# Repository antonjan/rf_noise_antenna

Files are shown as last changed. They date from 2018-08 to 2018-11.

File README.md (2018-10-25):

# rf_noise_antenna
This repository will have all the details for the active antenna board for Rasdpberry PI<br>
This project will have the Raspberry Pi HAT that will switch in the LOW and HIGH pass filters depending on IO-PIN4 on raspberry Pi.<br>
What is still missing from this project is the actual active antenna.<br>
<b>RF Noise Block Diagram</b><br>
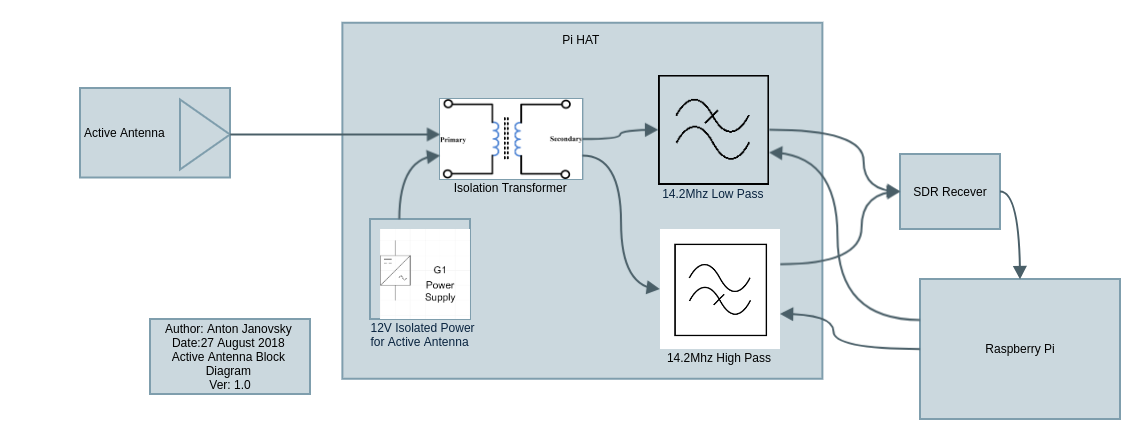
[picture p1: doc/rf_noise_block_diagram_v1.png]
Block Diagram Block Diagram
<br>
There is also a Isolation transformer on the board to eliminate the DC ground from the antenna and generating noise.<br>
This antenna consists of a raspberry HAT for RF filter and power injection for the active Antenna.<br>
<br>
# Project Status
This Project is Now Compleet. (The PCB Board still needs to be build and Tested)<br>
# Live Monitoring system
<a href="http://rfnoise.amsatsa.org.za/">http://rfnoise.amsatsa.org.za/</a><br>
# More Documentation
<a href="https://github.com/antonjan/rf_noise_antenna/tree/master/doc">More Dokuments click here</a><br>
<b>Diagram of Active antenna base filter.</b><br>
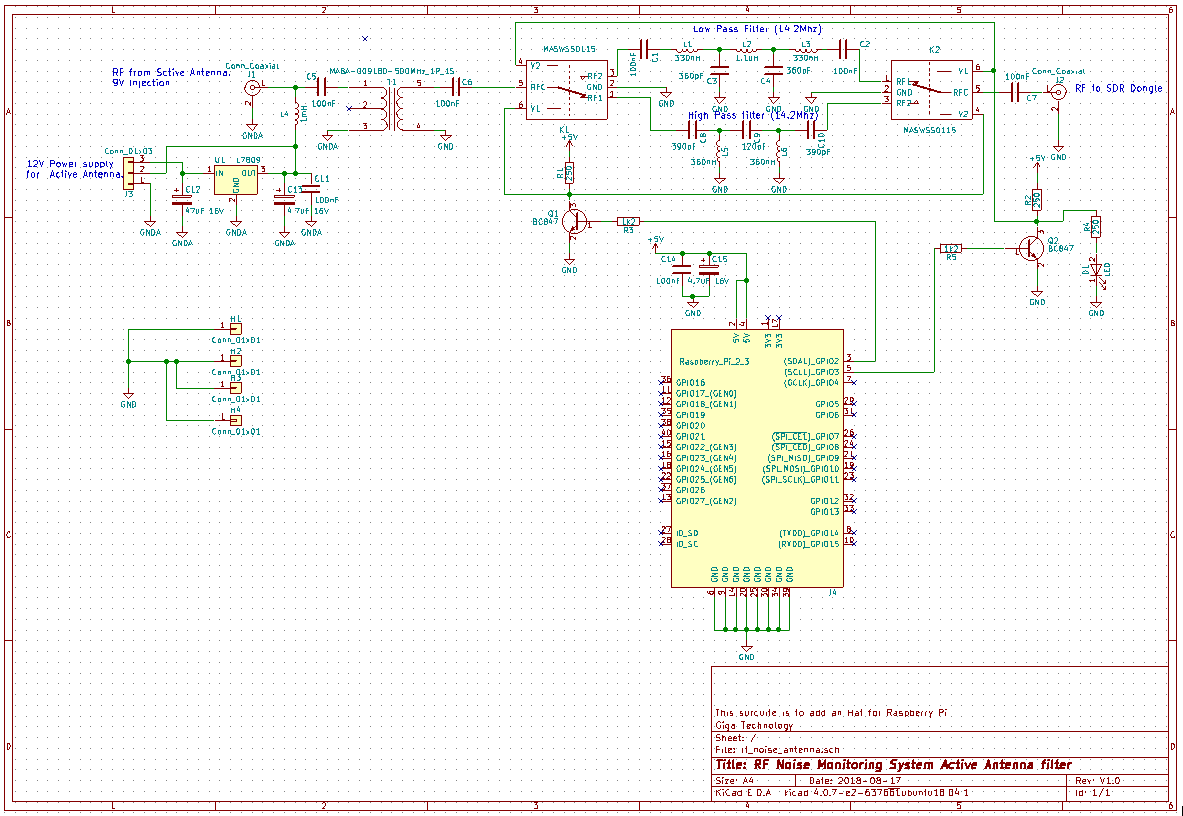
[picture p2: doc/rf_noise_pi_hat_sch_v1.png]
Diagram
<br><br>
PCB Layout<br>
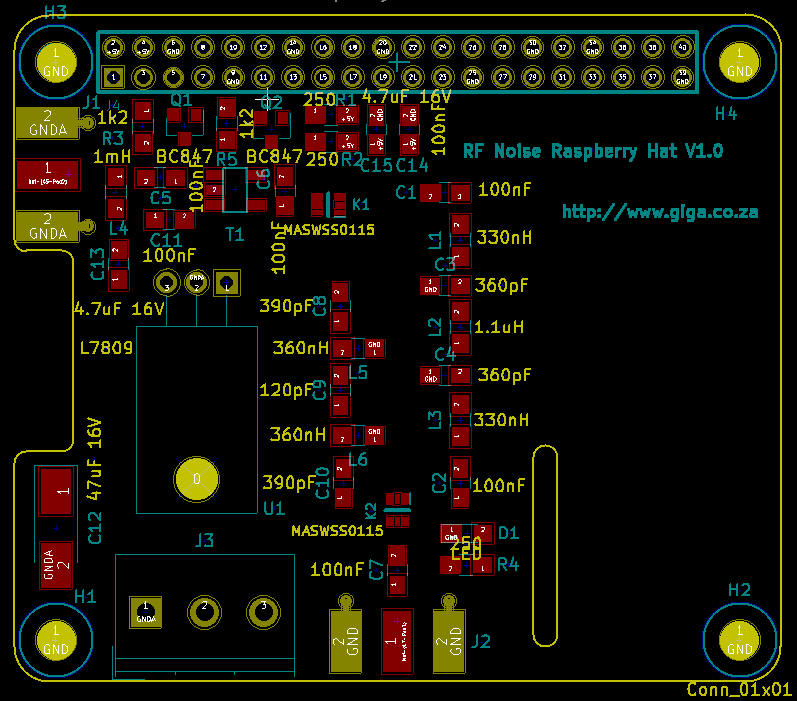
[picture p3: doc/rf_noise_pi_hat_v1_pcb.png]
<br><br>
<b>PCB Layout</b><br>
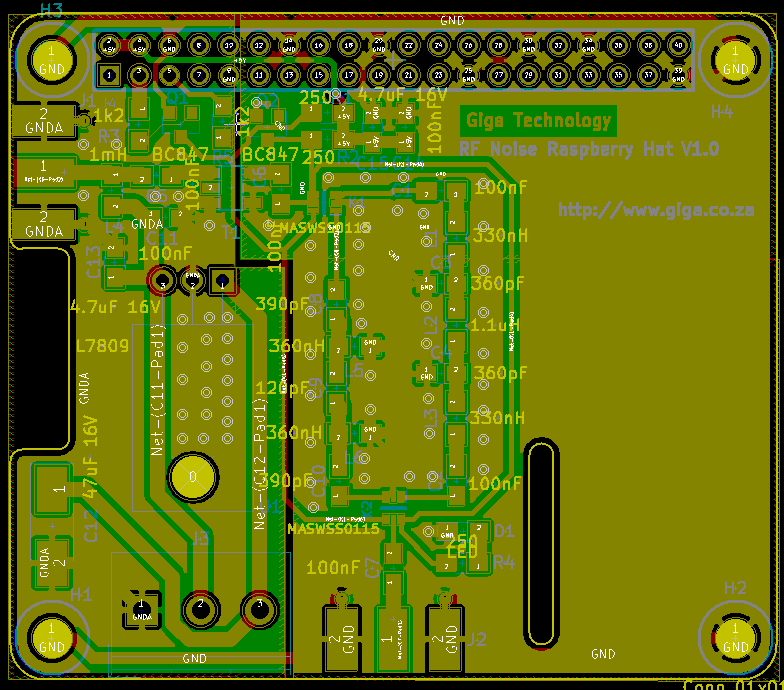
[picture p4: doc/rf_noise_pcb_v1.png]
<br><br>
<b>PCB Layout 3D</b><br>
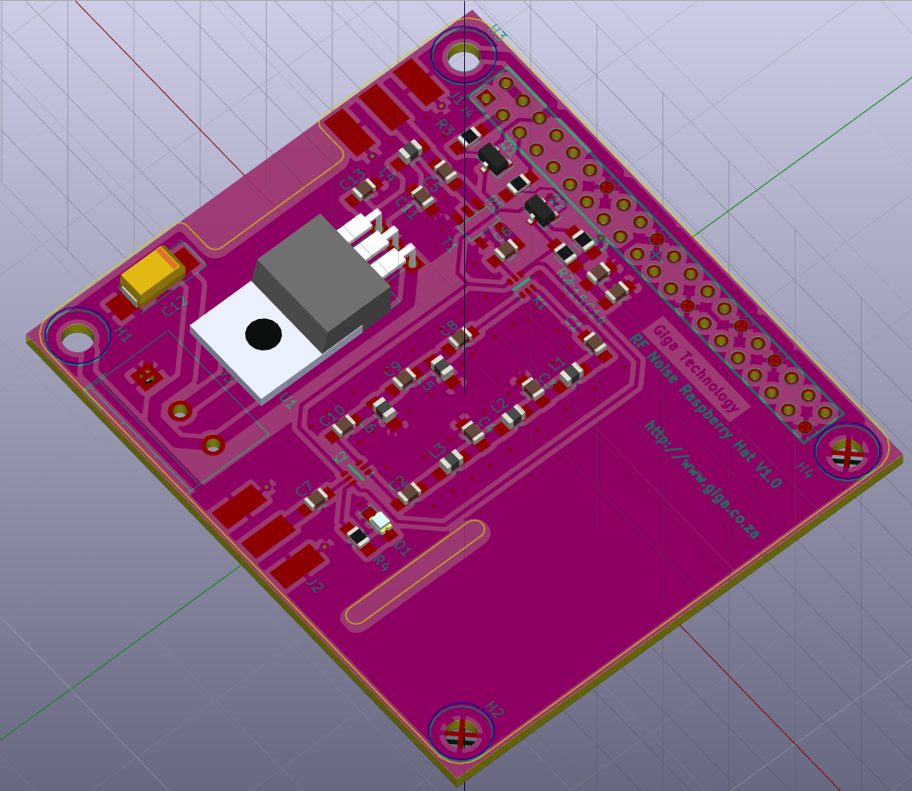
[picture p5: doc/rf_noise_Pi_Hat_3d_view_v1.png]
PCB PCB Layout 3D
<br><br>
<b>Filter Low PASS</b><br>
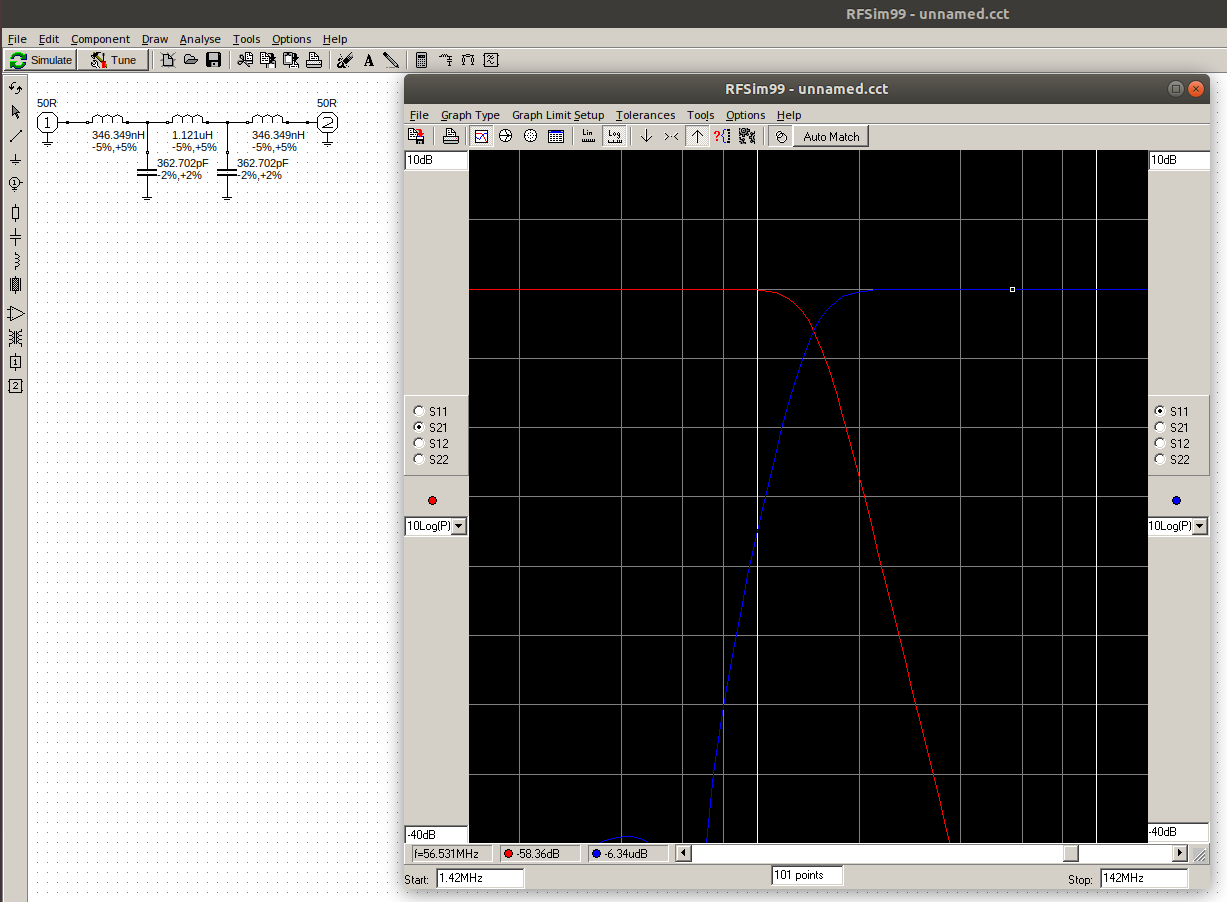
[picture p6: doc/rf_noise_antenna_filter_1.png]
Filter 1
<br><br>
<b>Filter High PASS</b><br>
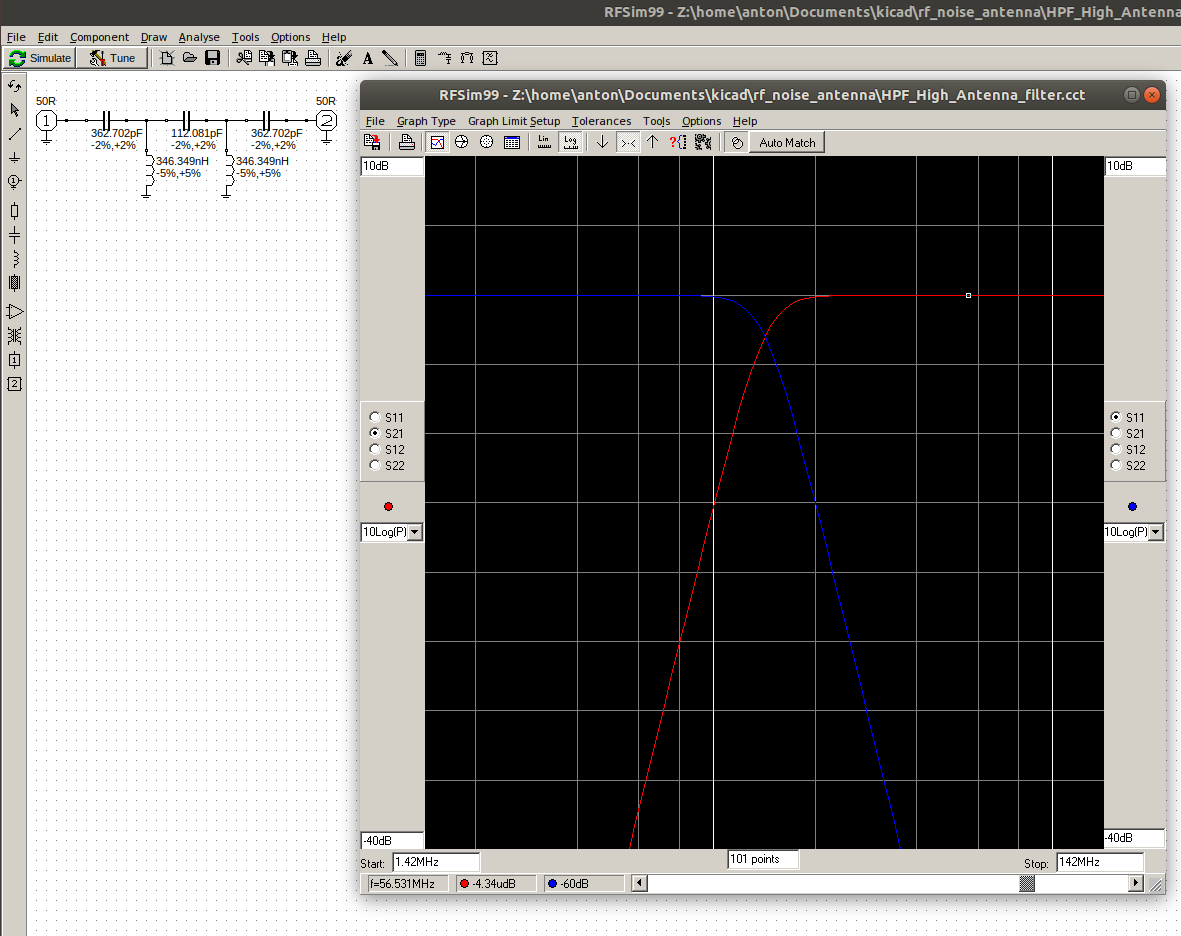
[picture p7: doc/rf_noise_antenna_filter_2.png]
Filter 2
<br><br>
<br>

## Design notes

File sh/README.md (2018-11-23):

# This testing scripts to controle the Antenna switch on RF Noise Antenna filter Board.
The antenna_loop_test.sh will swiche between the two antennas every 1 second just to test that the LED's activate

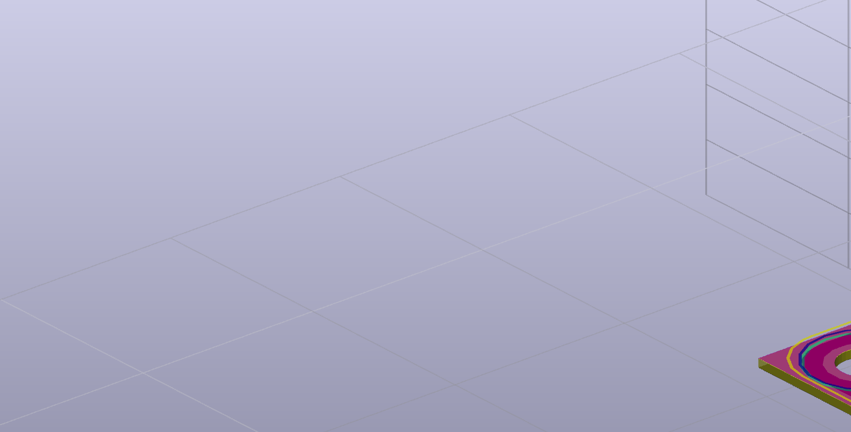
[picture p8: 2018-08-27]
doc/rf_noise_antenna_3d_view_v1.png

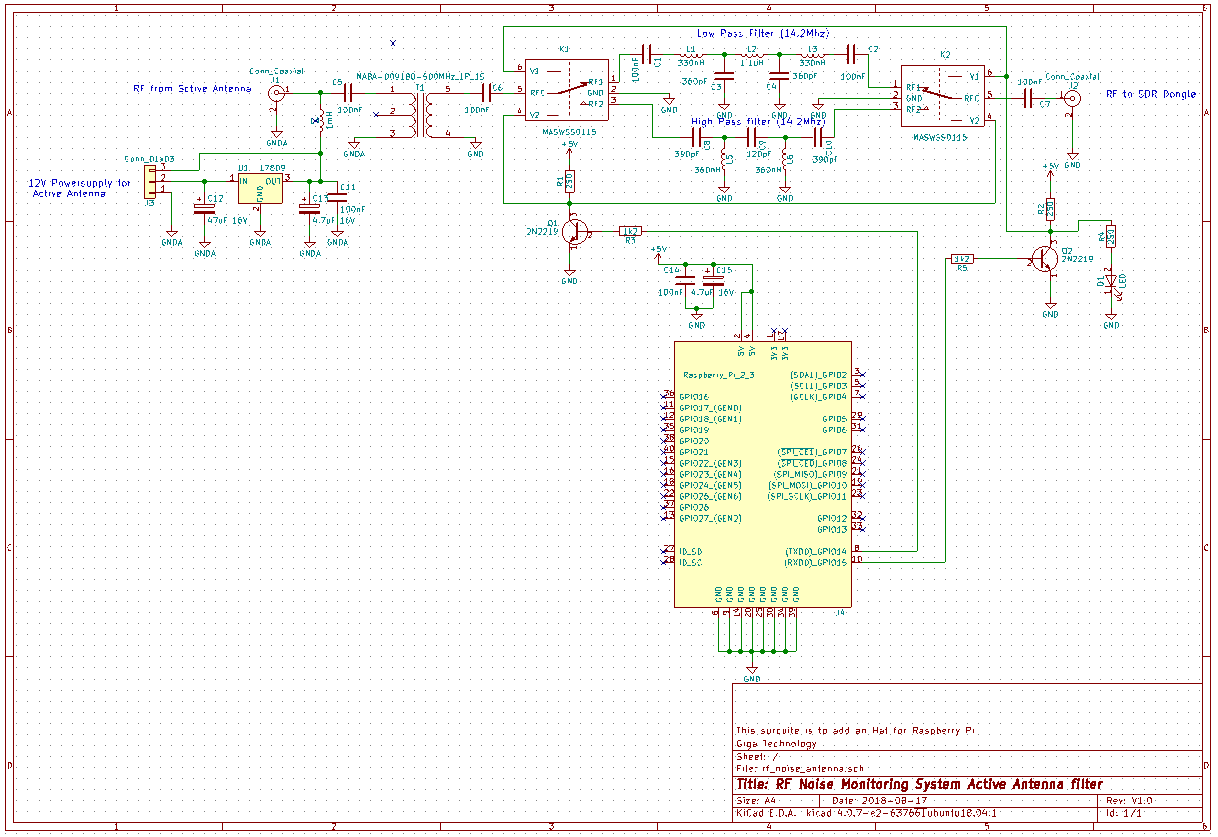
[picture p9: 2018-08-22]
doc/rf_noise_antenna_3.png

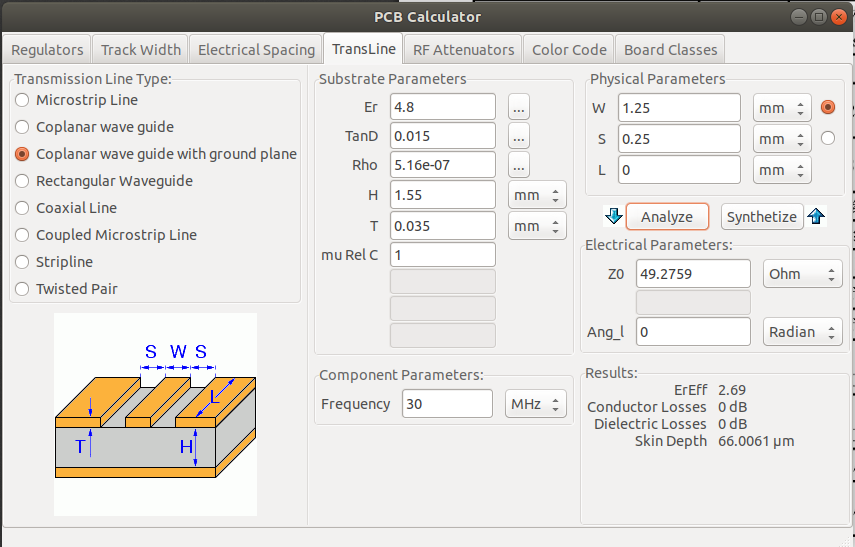
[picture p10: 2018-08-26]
doc/Transmition_Line_30Mhz.png

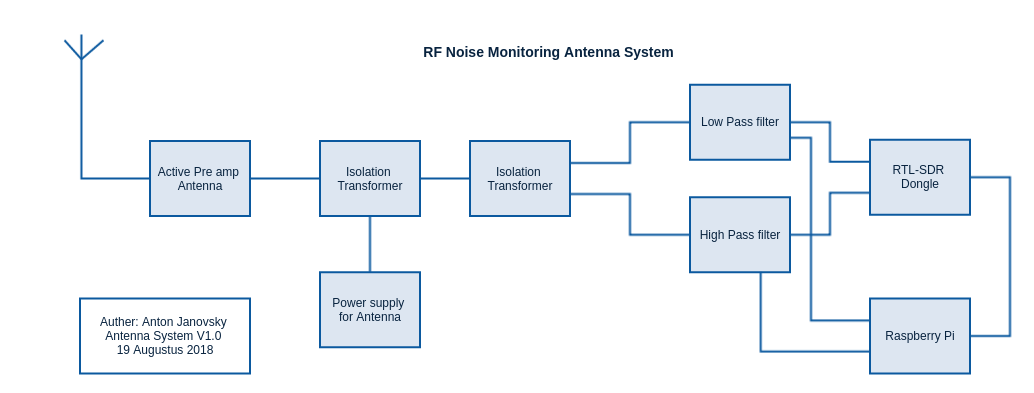
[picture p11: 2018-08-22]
gliffy/RF_Antenna_System_v1_0.png

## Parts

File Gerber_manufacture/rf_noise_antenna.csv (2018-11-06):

Id | Designator | Package | Quantity | Designation | Supplier and ref
1 | J1,J2 | Molex_SMA_Jack_Edge_Mount | 2 | Conn_Coaxial
2 | J4 | PIN_ARRAY_20X2 | 1 | Raspberry_Pi_2_3
3 | C1,C2,C5,C6,C7,C11,C14 | C_0805_HandSoldering | 7 | 100nF
4 | C3,C4 | C_0805_HandSoldering | 2 | 360pF
5 | C8,C10 | C_0805_HandSoldering | 2 | 390pF
6 | C9 | C_0805_HandSoldering | 1 | 120pF
7 | C12 | CP_Tantalum_Case-C_EIA-6032-28_Hand | 1 | 47uF 16V
8 | C13,C15 | C_0805_HandSoldering | 2 | 4.7uF 16V
9 | D1 | LED_0805_HandSoldering | 1 | LED
10 | J3 | TerminalBlock_Philmore_TB133_03x5mm_Straight | 1 | Conn_01x03
11 | K1,K2 | SC-70-6 | 2 | MASWSS0115
12 | L1,L3 | L_0805_HandSoldering | 2 | 330nH
13 | L2 | L_0805_HandSoldering | 1 | 1.1uH
14 | L4 | L_0805_HandSoldering | 1 | 1mH
15 | L5,L6 | L_0805_HandSoldering | 2 | 360nH
16 | R1,R2,R4 | R_0805_HandSoldering | 3 | 250
17 | R3,R5 | R_0805_HandSoldering | 2 | 1k2
18 | T1 | SM22 | 1 | MABA-009180-500MHz_1P_1S
19 | H1,H2,H3,H4 | MountingHole_3.2mm_M3 | 4 | Conn_01x01
20 | Q1,Q2 | SOT-23 | 2 | BC847
21 | U1 | TO-220_Horizontal | 1 | L7809

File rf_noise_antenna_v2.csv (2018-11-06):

Id | Designator | Package | Quantity | Designation | Supplier and ref
1 | J4 | PIN_ARRAY_20X2 | 1 | Raspberry_Pi_2_3
2 | C1,C2,C5,C6,C7,C11,C14 | C_0805_HandSoldering | 7 | 100nF
3 | C3,C4 | C_0805_HandSoldering | 2 | 360pF
4 | C8,C10 | C_0805_HandSoldering | 2 | 390pF
5 | C9 | C_0805_HandSoldering | 1 | 120pF
6 | C12 | CP_Tantalum_Case-C_EIA-6032-28_Hand | 1 | 47uF 16V
7 | C13,C15 | C_0805_HandSoldering | 2 | 4.7uF 16V
8 | D1,D2 | LED_0805_HandSoldering | 2 | LED
9 | J3 | TerminalBlock_Philmore_TB133_03x5mm_Straight | 1 | Conn_01x03
10 | K1,K2 | SC-70-6 | 2 | MASWSS0115
11 | L1,L3 | L_0805_HandSoldering | 2 | 330nH
12 | L2 | L_0805_HandSoldering | 1 | 1.1uH
13 | L4 | L_0805_HandSoldering | 1 | 10uH
14 | L5,L6 | L_0805_HandSoldering | 2 | 360nH
15 | R1,R2,R4,R6 | R_0805_HandSoldering | 4 | 250
16 | R3,R5 | R_0805_HandSoldering | 2 | 1k2
17 | T1 | SM22 | 1 | MABA-009180-500MHz_1P_1S
18 | H1,H2,H3,H4 | MountingHole_3.2mm_M3 | 4 | Conn_01x01
19 | Q1,Q2 | SOT-23 | 2 | BC847
20 | U1 | TO-220_Horizontal | 1 | L7812
21 | J1,J2 | SMA_Edge | 2 | Conn_Coaxial
22 | REF**,REF**,REF**,REF** | MountingHole_3.2mm_M3 | 4 | MountingHole_3.2mm_M3

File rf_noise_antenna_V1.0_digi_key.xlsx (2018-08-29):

Component | Description | Manufacturere Pnr | Part | References | Value | Footprint | Quantity Per PCB | Datasheet
1 | Unpolarized capacitor | 399-1122-1-ND (https://www.digikey.co.za/product-detail/en/kemet/C0805C101J5GACTU/399-1122-1-ND/411397) | C | C1 C2 C5 C6 C7 C11 C14 | 100nF | C_0805_HandSoldering | 7
2 | Unpolarized capacitor | 1276-1768-1-ND (https://www.digikey.co.za/product-detail/en/samsung-electro-mechanics/CL21C121JBANNNC/1276-1768-1-ND/3889854) | C | C9 | 120pF | C_0805_HandSoldering | 1
3 | Unpolarized capacitor | 1276-2650-1-ND (https://www.digikey.co.za/product-detail/en/samsung-electro-mechanics/CL21C361JBANNNC/1276-2650-1-ND/3890736) | C | C3 C4 | 360pF | C_0805_HandSoldering | 2
4 | Unpolarized capacitor | 1276-2510-1-ND (https://www.digikey.co.za/product-detail/en/samsung-electro-mechanics/CL21B391KBANNNC/1276-2510-1-ND/3890596) | C | C8 C10 | 390pF | C_0805_HandSoldering | 2
5 | Polarised capacitor | 1276-1065-1-ND (https://www.digikey.co.za/product-detail/en/samsung-electro-mechanics/CL21A475KOFNNNE/1276-1065-1-ND/3889151) | CP | C13 C15 | 4.7uF 16V | C_0805_HandSoldering | 2
6 | Polarised capacitor | 718-1042-1-ND (https://www.digikey.co.za/product-detail/en/vishay-sprague/293D106X0016C2TE3/718-1042-1-ND/1559536) | CP | C12 | 47uF 16V | CP_Tantalum_Case-C_EIA-6032-28_Hand | 1
7 | LED generic | 67-1710-1-ND (https://www.digikey.co.za/product-detail/en/lumex-opto-components-inc/SML-LXR85SIC-TR/67-1710-1-ND/467594) | LED | D1 D2 | LED | LED_0805_HandSoldering | 2
8 | Generic connector, single row, 01x03 | 732-5316-ND (https://www.digikey.co.za/product-detail/en/wurth-electronics-inc/61300311121/732-5316-ND/4846825) | Conn_01x03 | J3 | Conn_01x03 | TerminalBlock_Philmore_TB133_03x5mm_Straight | 1
9 | coaxial connector (BNC, SMA, SMB, SMC, Cinch/RCA, ...) | 931-1175-ND (https://www.digikey.co.za/product-detail/en/taoglas-limited/EMPCB.SMAFSTJ.B.HT/931-1175-ND/3522337) | Conn_Coaxial | J1 J2 | Conn_Coaxial | Molex_SMA_Jack_Edge_Mount | 2
10 | expansion header for Raspberry Pi 2 & 3 | S6106-ND (https://www.digikey.co.za/product-detail/en/sullins-connector-solutions/PPPC102LFBN-RC/S6106-ND/807245) | Raspberry_Pi_2_3 | J4 | Raspberry_Pi_2_3 | Pin_Header_Straight_2x20 | 1 | https://www.raspberrypi.org/documentation/hardware/raspberrypi/schematics/RPI-3B-V1_2-SCHEMATIC-REDUCED.pdf
11 |  | 1465-1373-1-ND (https://www.digikey.co.za/product-detail/en/m-a-com-technology-solutions/MASWSS0115TR-3000/1465-1373-1-ND/4430070) | MASWSS0115 | K1 K2 | MASWSS0115 | SC-70-6 | 2
12 | Inductor | 963-LBR2012T1R0M (https://www.mouser.co.za/ProductDetail/Taiyo-Yuden/LBR2012T1R0M) | L | L2 | 1.1uH (get only 1uH) | L_0805_HandSoldering | 1 | https://www.mouser.co.za/ProductDetail/Taiyo-Yuden/LBR2012T1R0M
13 | Inductor | 652-CV201210-100K (https://www.mouser.co.za/ProductDetail/Bourns/CV201210-100K) | L | L4 | 10uH | L_0805_HandSoldering | 1
14 | Inductor | 652-CE201210-R33J (https://www.mouser.co.za/ProductDetail/Bourns/CE201210-R33J) | L | L1 L3 | 330nH | L_0805_HandSoldering | 2
15 | Inductor | 279-36502AR36JTDG (https://www.mouser.co.za/ProductDetail/TE-Connectivity-Sigma-Inductors/36502AR36JTDG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) | L | L5 L6 | 360nH | L_0805_HandSoldering | 2
16 | 45V Vce, 0.8A Ic, NPN, SOT-23 | BC847BRFGCT-ND (https://www.digikey.co.za/product-detail/en/taiwan-semiconductor-corporation/BC847B-RFG/BC847BRFGCT-ND/7357201) | BC847 | Q1 Q2 | BC847 | SOT-23 | 2 | http://www.fairchildsemi.com/ds/BC/BC817.pdf
17 | Resistor | 311-1.27KCRCT-ND (https://www.digikey.co.za/product-detail/en/yageo/RC0805FR-071K27L/311-1.27KCRCT-ND/730422) | R | R3 R5 | 1k2 | R_0805_HandSoldering | 2
18 | Resistor | RHM.27BSCT-ND (https://www.digikey.co.za/product-detail/en/rohm-semiconductor/LTR10EVHFLR270/RHM.27BSCT-ND/2708204) | R | R1 R2 R4 R6 | 250 | R_0805_HandSoldering | 4
19 | Transformer, single primary, single secondary | 1465-1793-1-ND (https://www.digikey.co.za/product-detail/en/m-a-com-technology-solutions/MABA-009180-500MHZ/1465-1793-1-ND/6575493) | MABA-009180-500MHz_1P_1S | T1 | MABA-009180-500MHz_1P_1S | SM22 | 1
20 | Positive 1.5A 35V Linear Regulator, Fixed Output 5V, TO-220/TO-263/TO-252 | LM7809ACT-ND (https://www.digikey.co.za/product-detail/en/on-semiconductor/LM7809ACT/LM7809ACT-ND/1923048) | L7809 | U1 | L7809 | TO-220_Horizontal | 1 | http://www.st.com/content/ccc/resource/technical/document/datasheet/41/4f/b3/b0/12/d4/47/88/CD00000444.pdf/files/CD00000444.pdf/jcr:content/translations/en.CD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
Component Groups: | 20
Component Count: | 39
Fitted Components: | 39
Number of PCBs: | 1
Total components: | 39
Schematic Version: | V1.0
Schematic Date: | 2018-08-17
BoM Date: | Wed 29 Aug 2018 09:54:15 SAST
Schematic Source: | /home/anton/Documents/kicad/rf_noise_antenna/rf_noise_antenna.sch
KiCad Version: | Eeschema 4.0.7-e2-6376~61~ubuntu18.04.1

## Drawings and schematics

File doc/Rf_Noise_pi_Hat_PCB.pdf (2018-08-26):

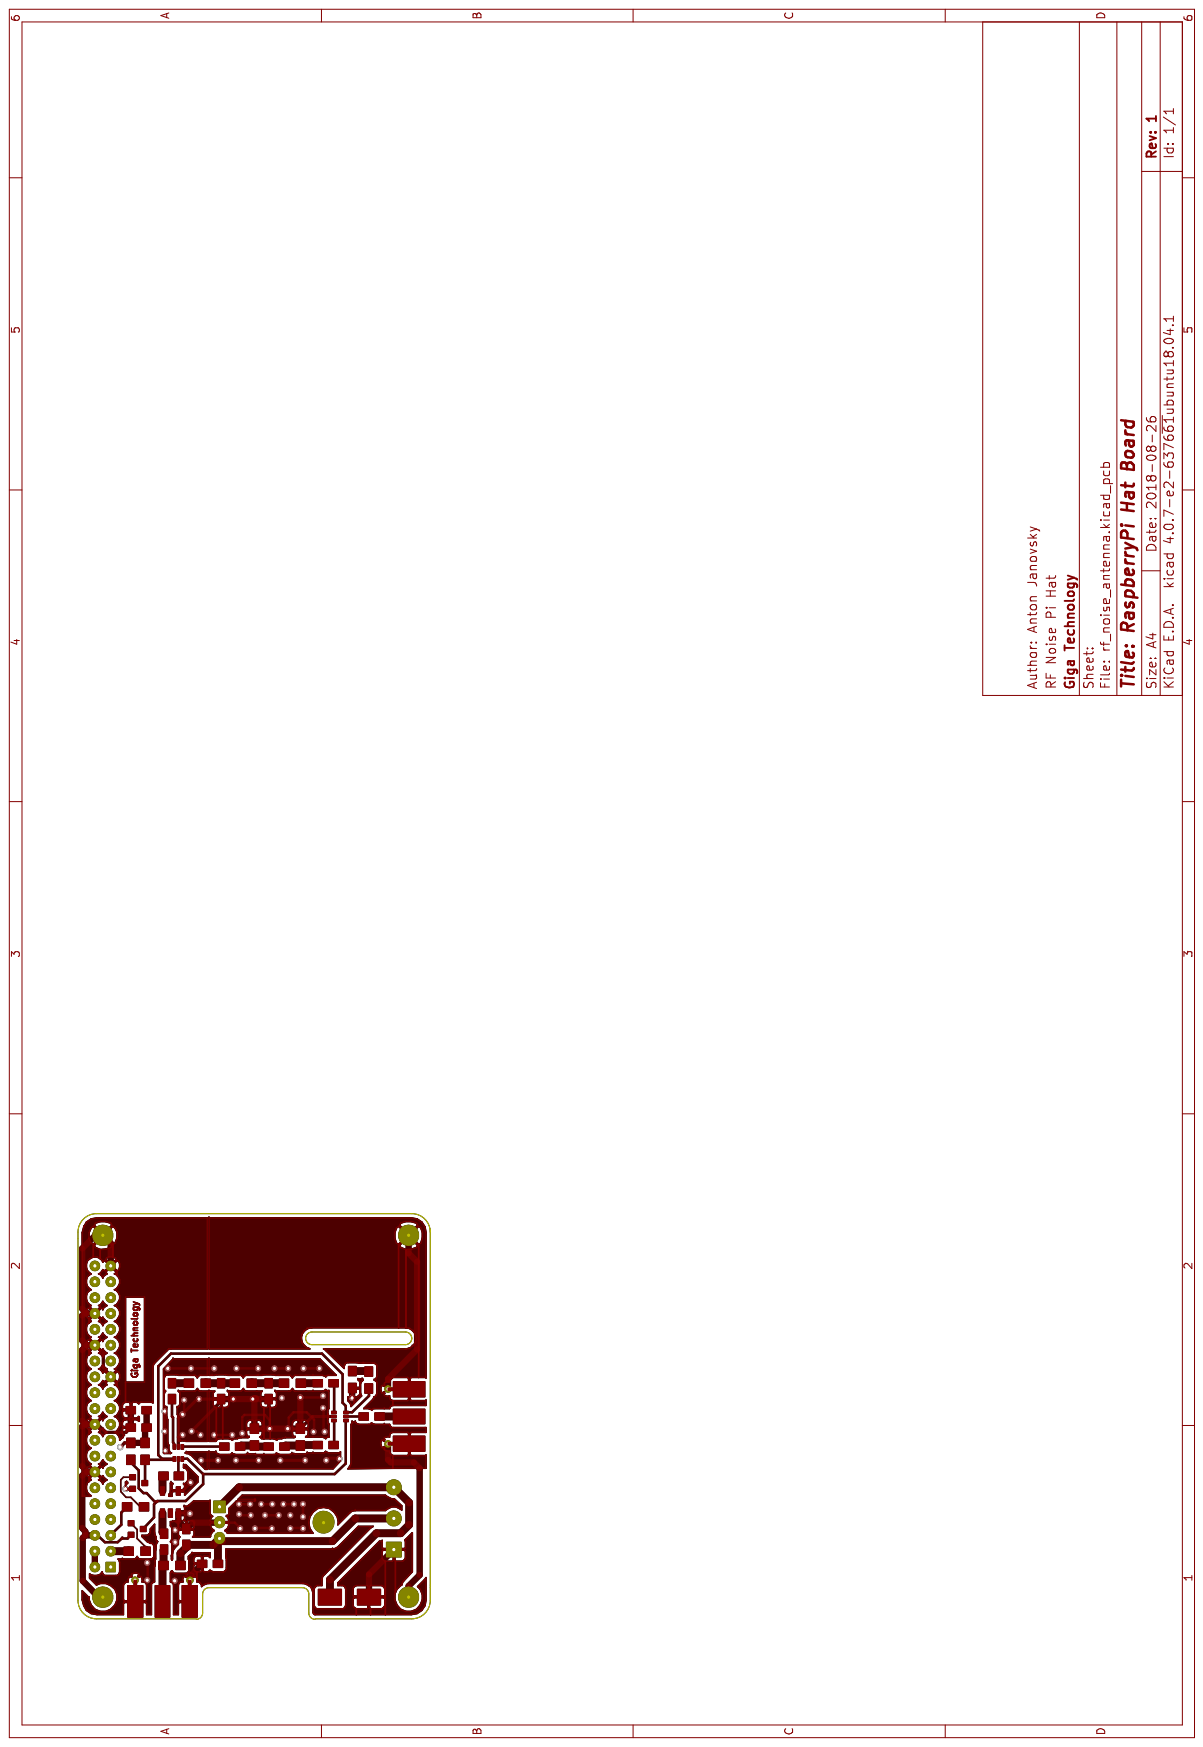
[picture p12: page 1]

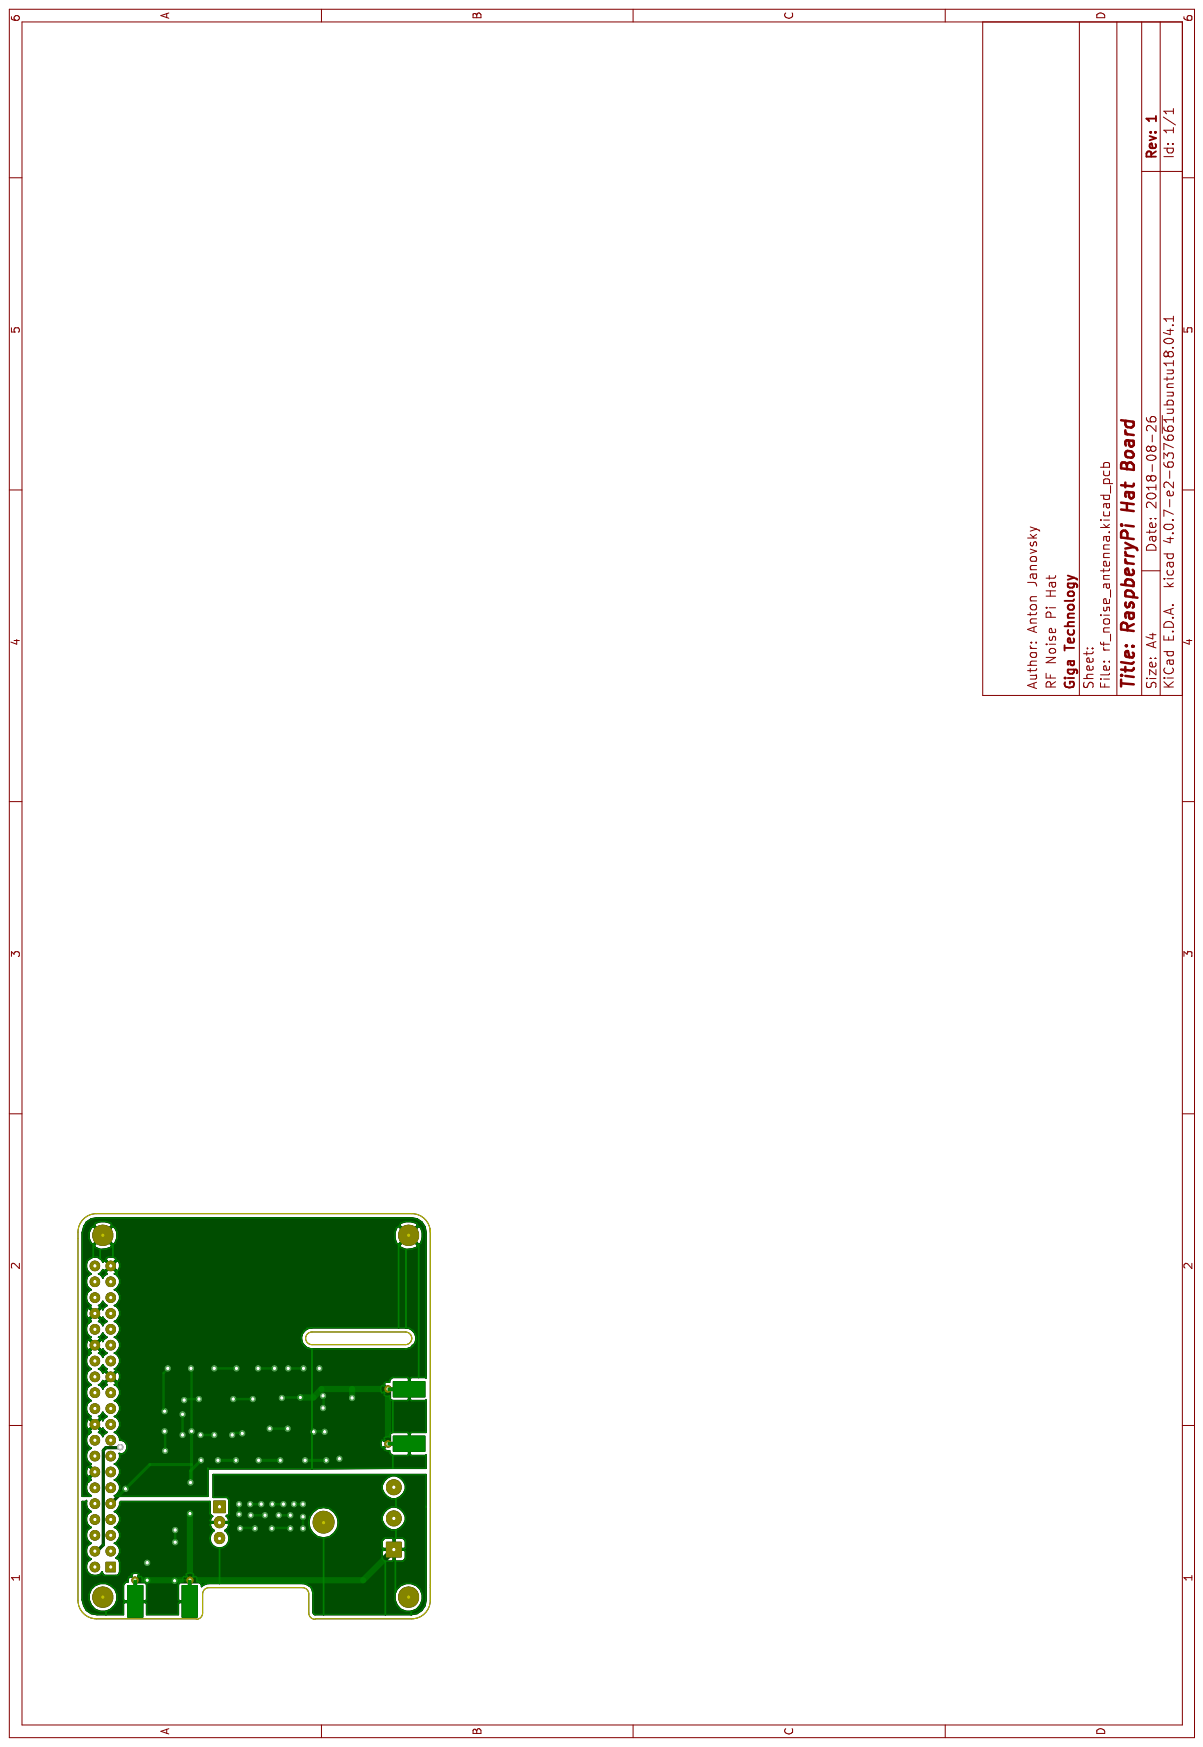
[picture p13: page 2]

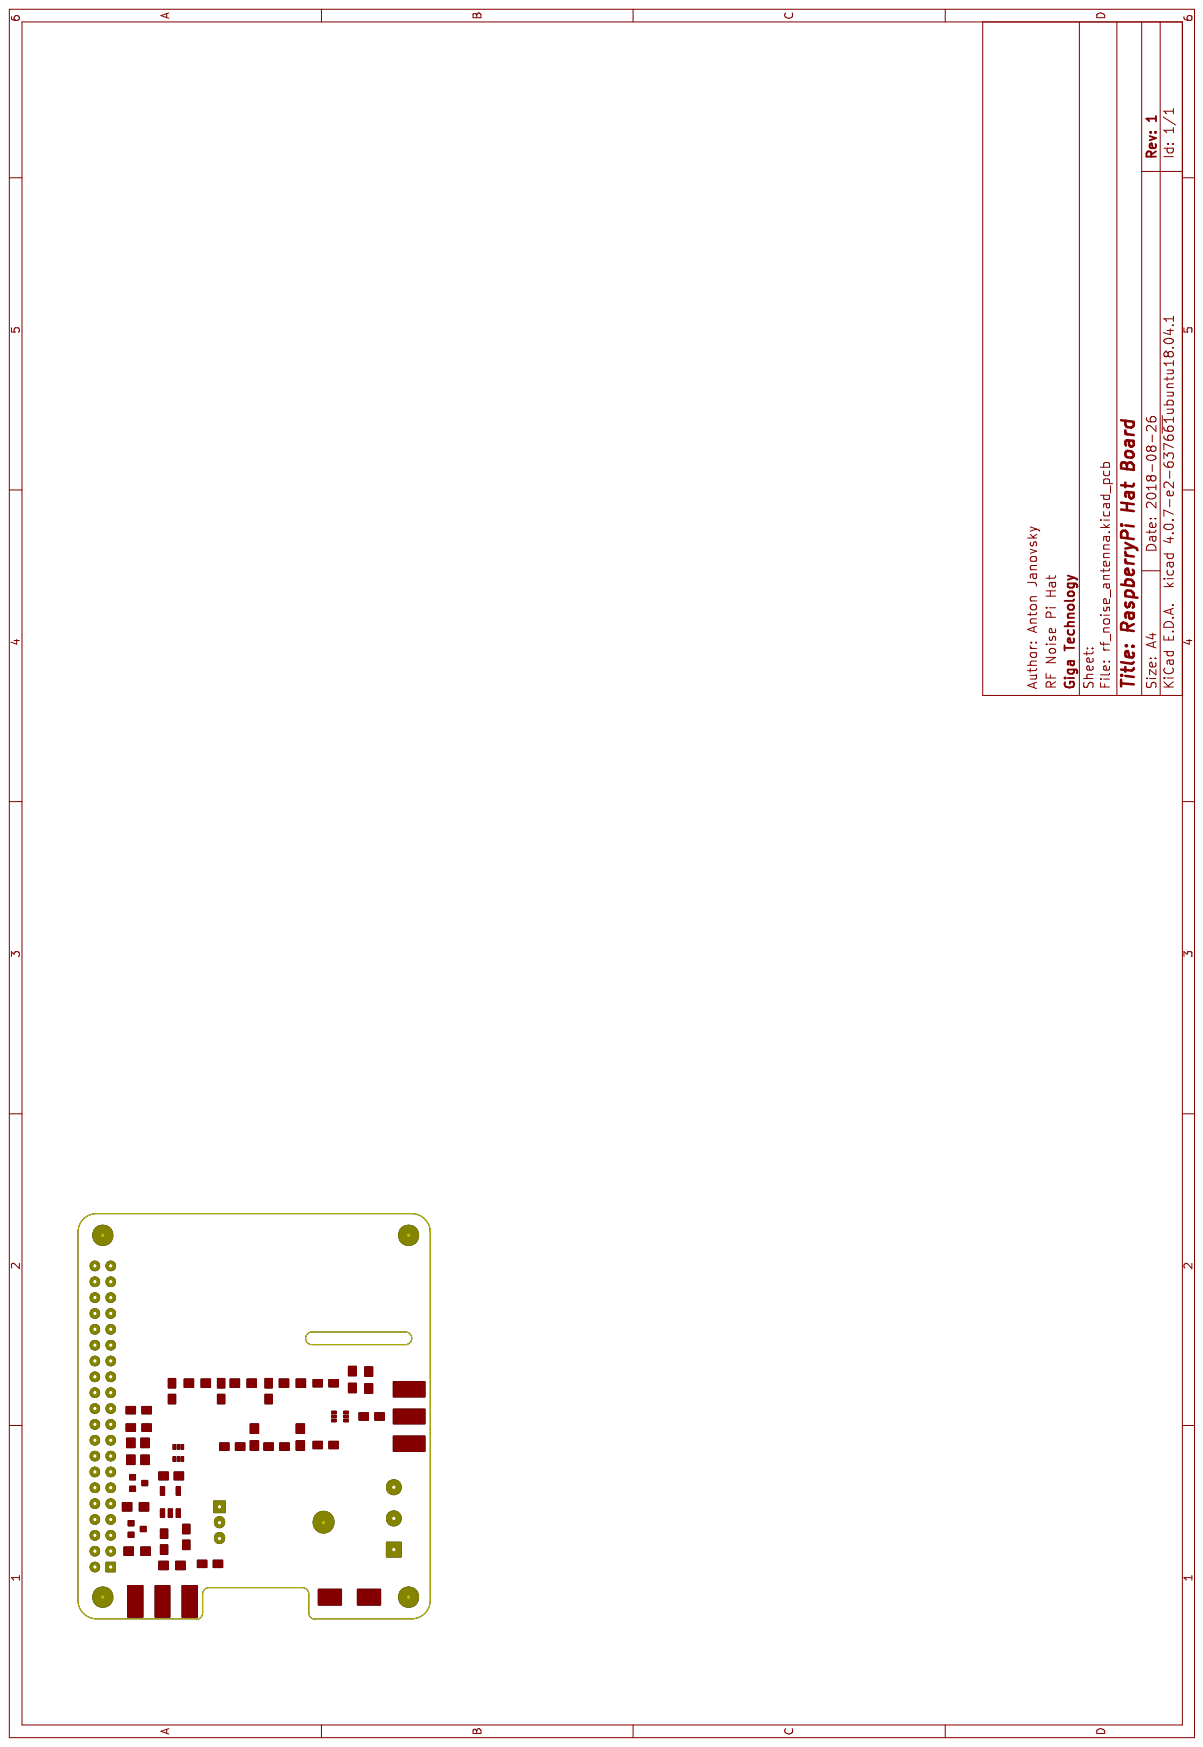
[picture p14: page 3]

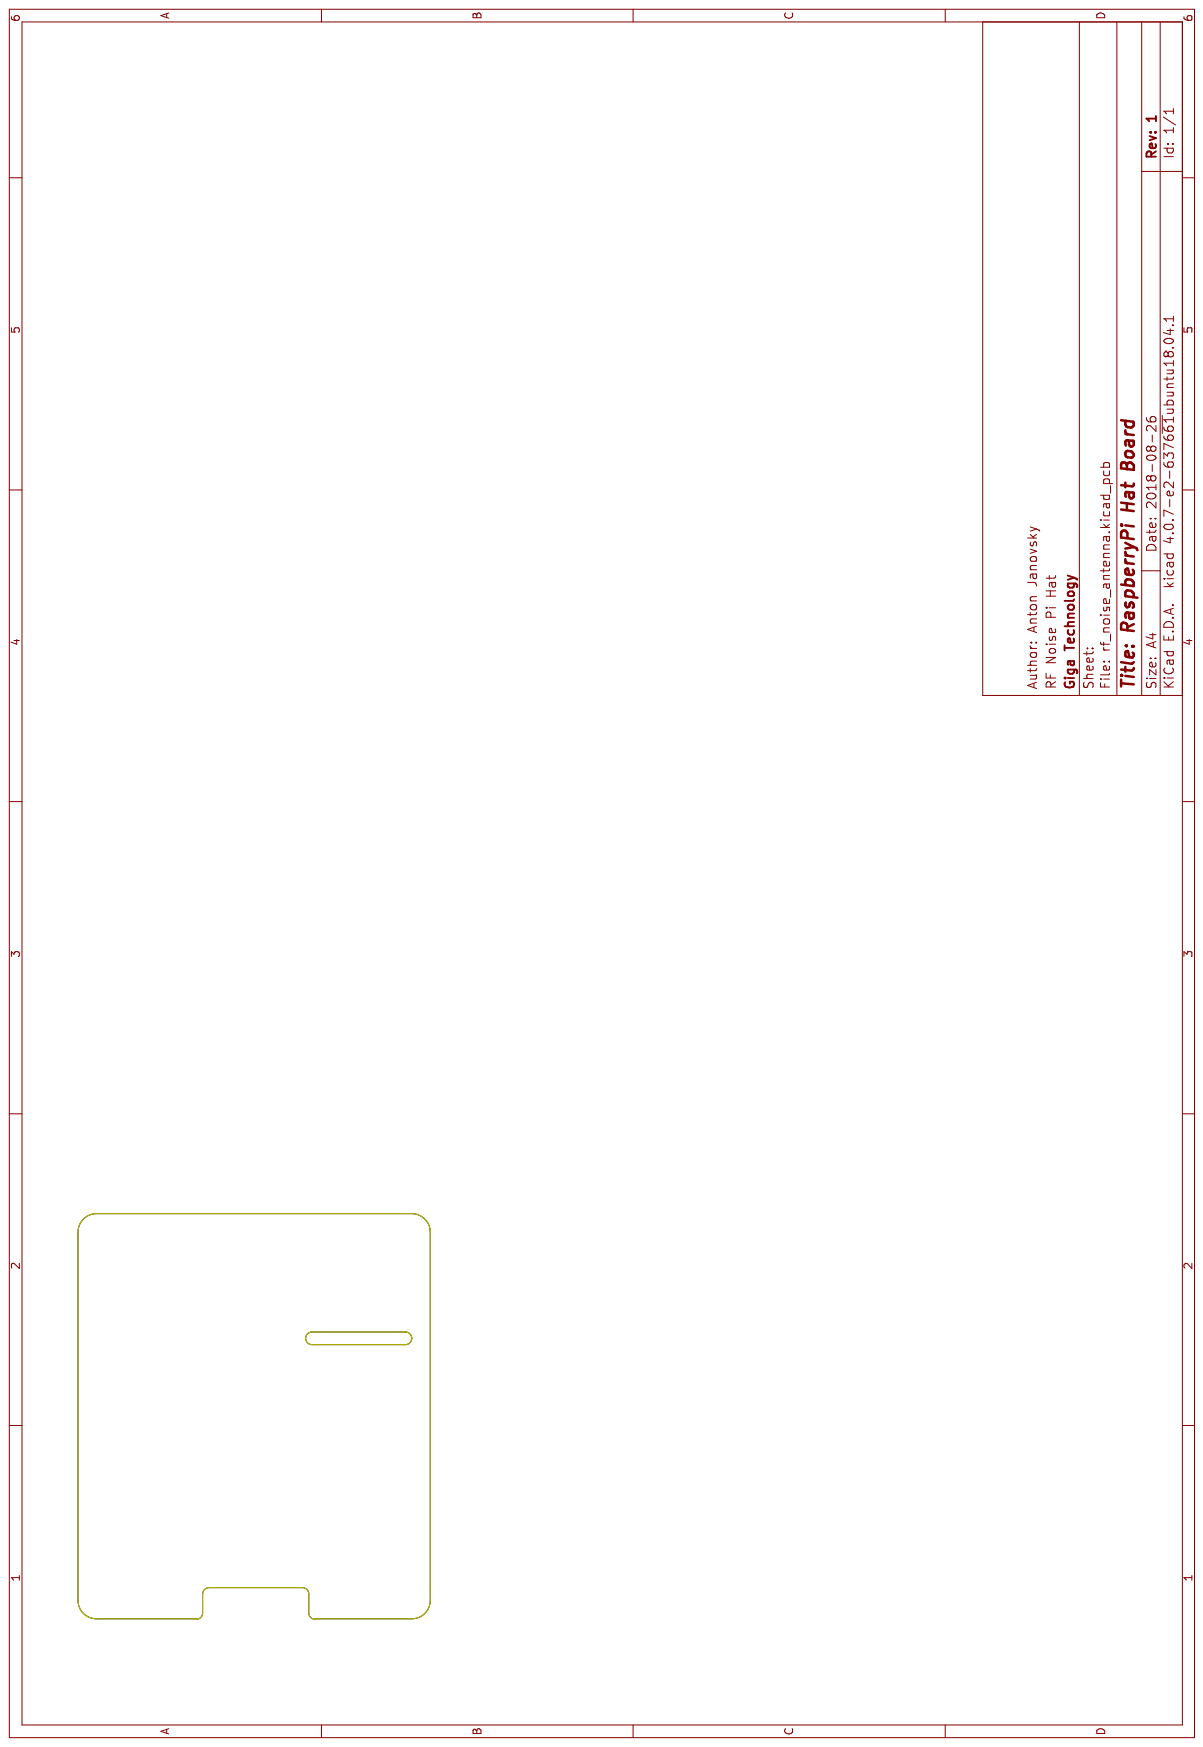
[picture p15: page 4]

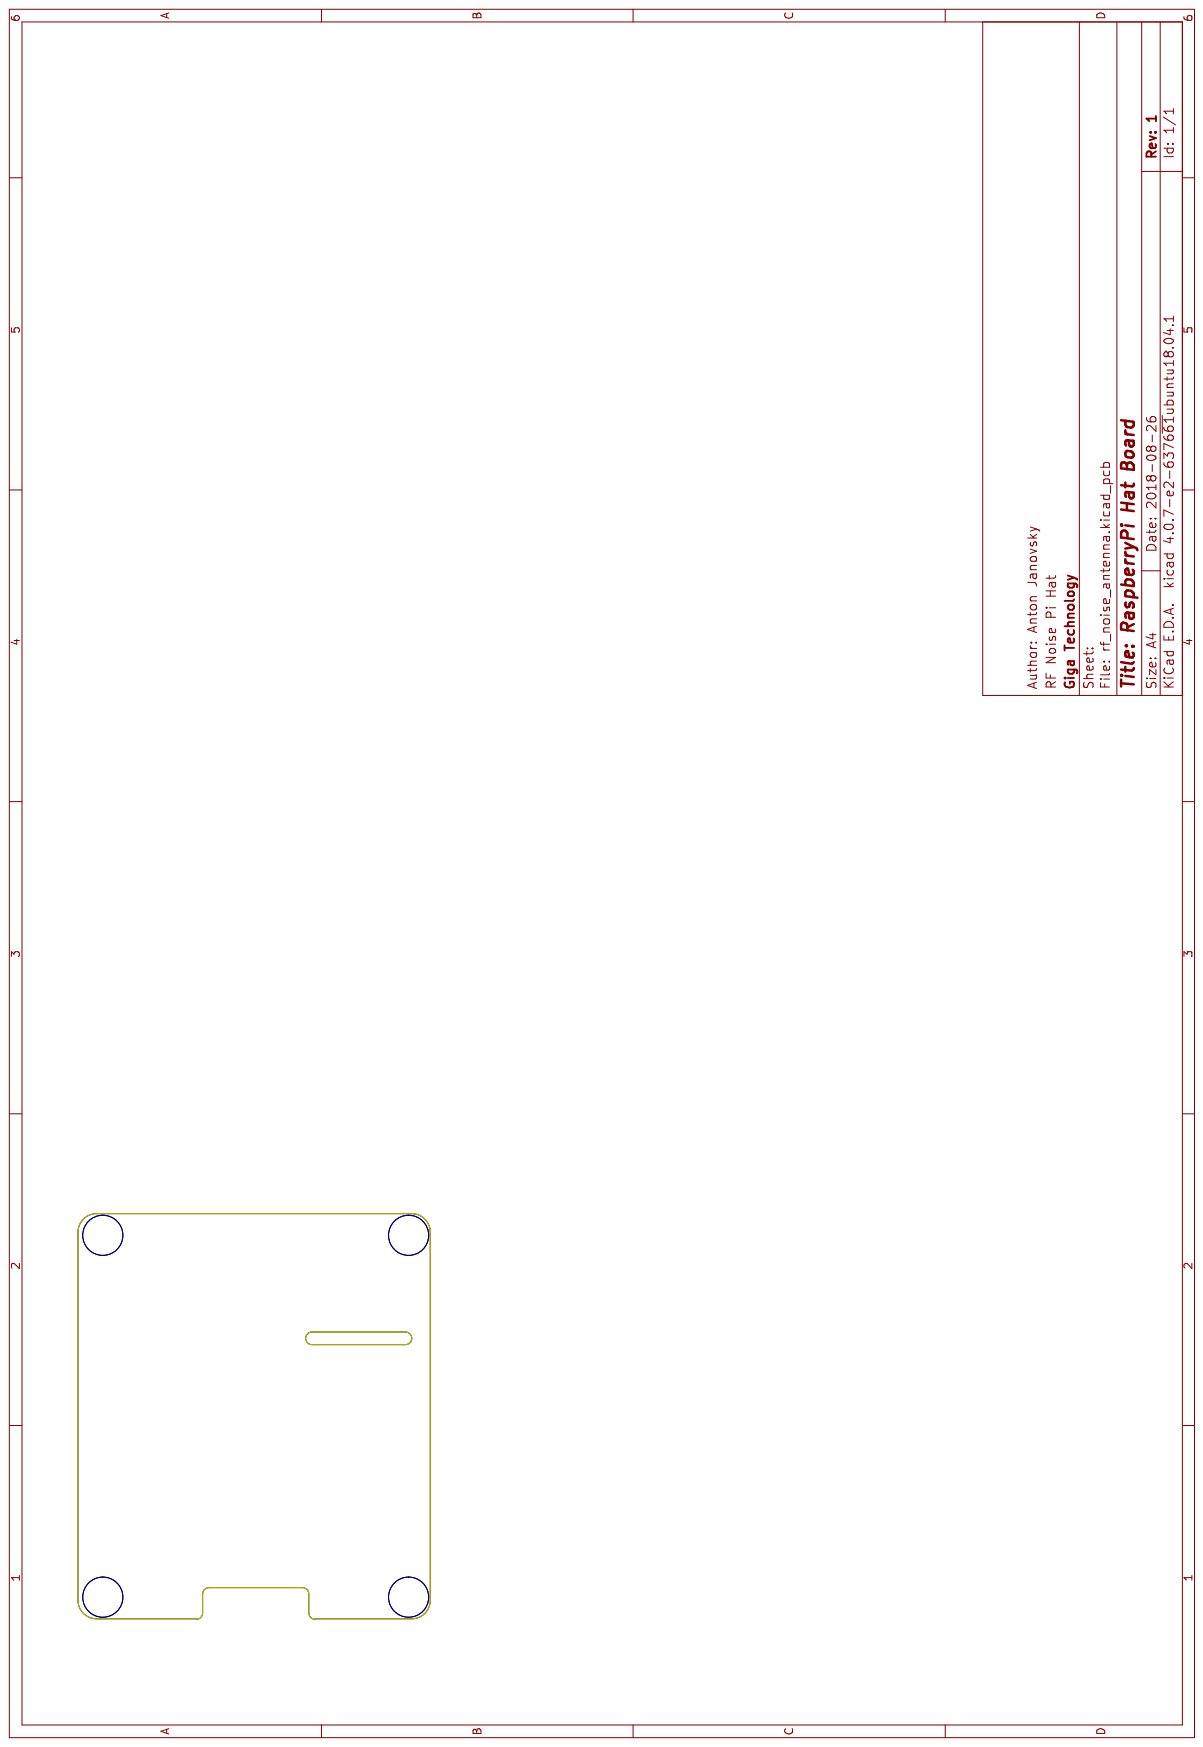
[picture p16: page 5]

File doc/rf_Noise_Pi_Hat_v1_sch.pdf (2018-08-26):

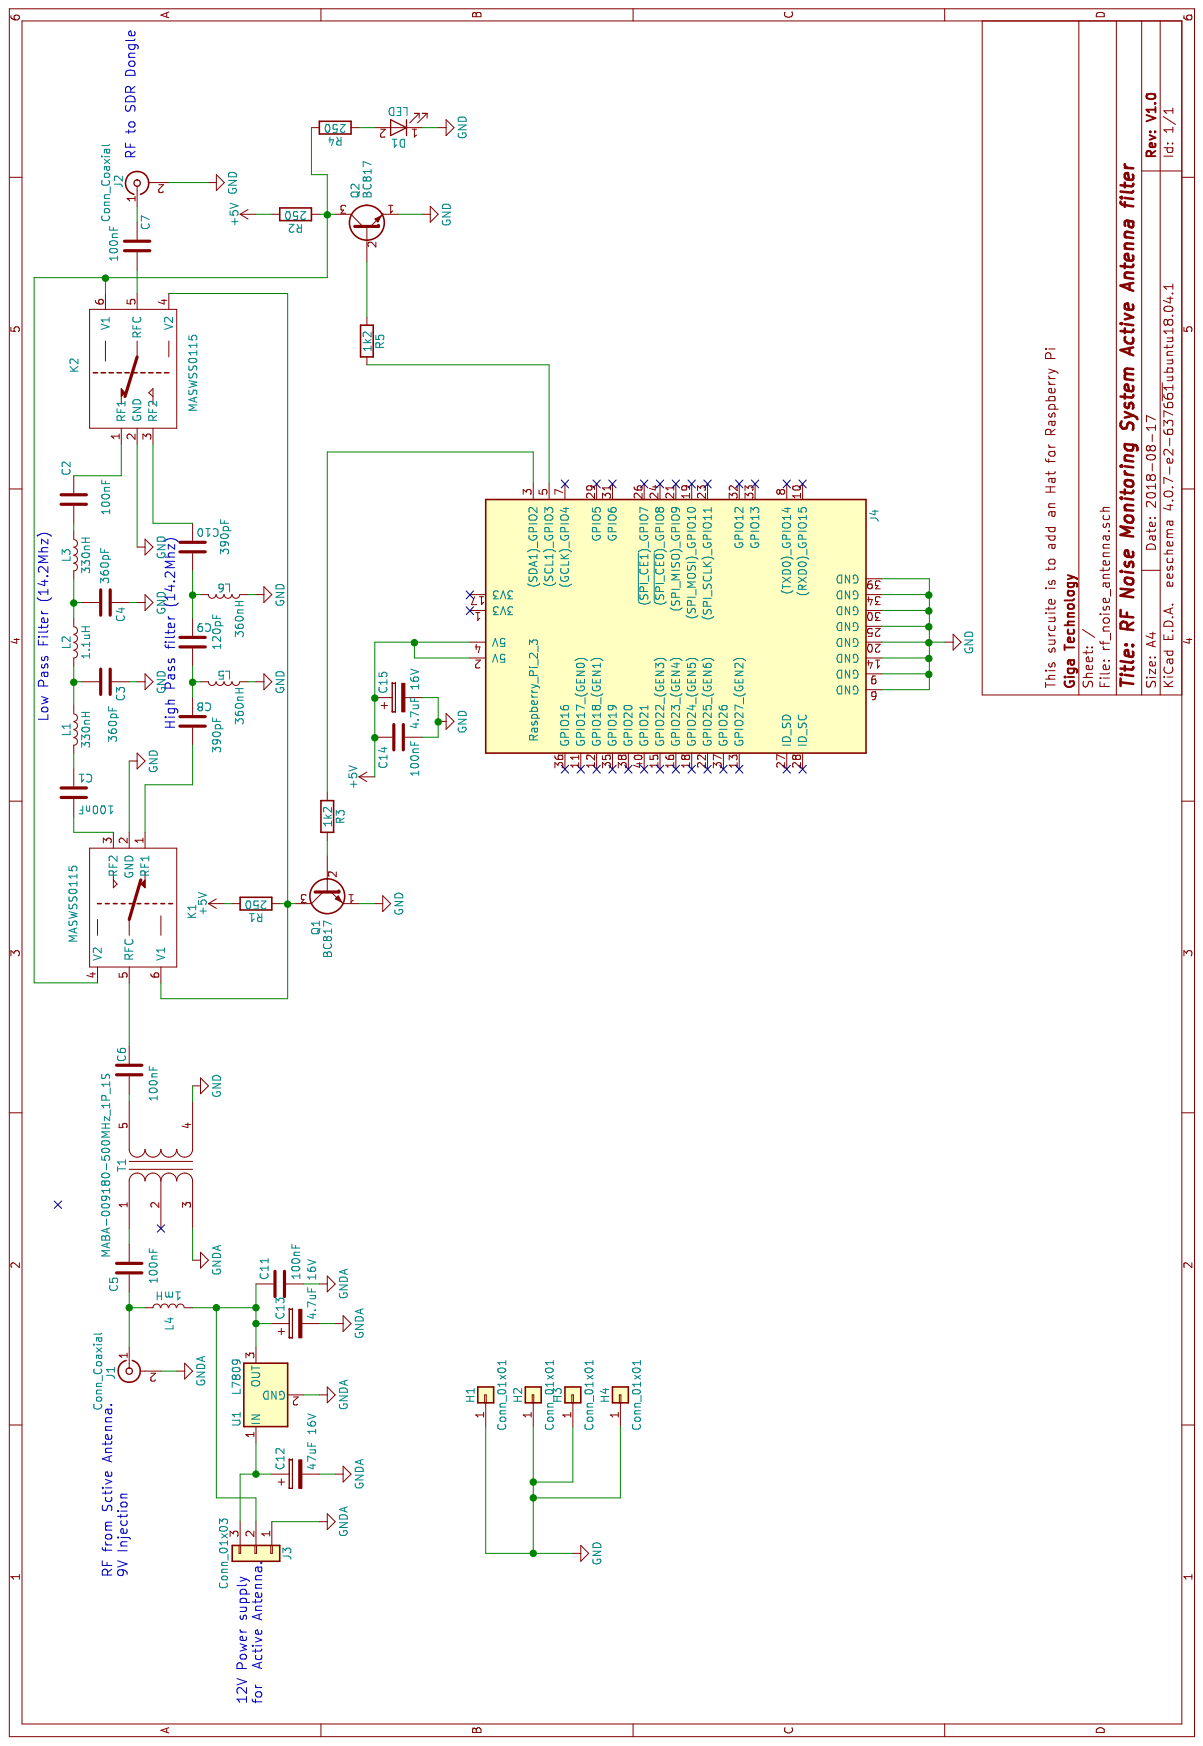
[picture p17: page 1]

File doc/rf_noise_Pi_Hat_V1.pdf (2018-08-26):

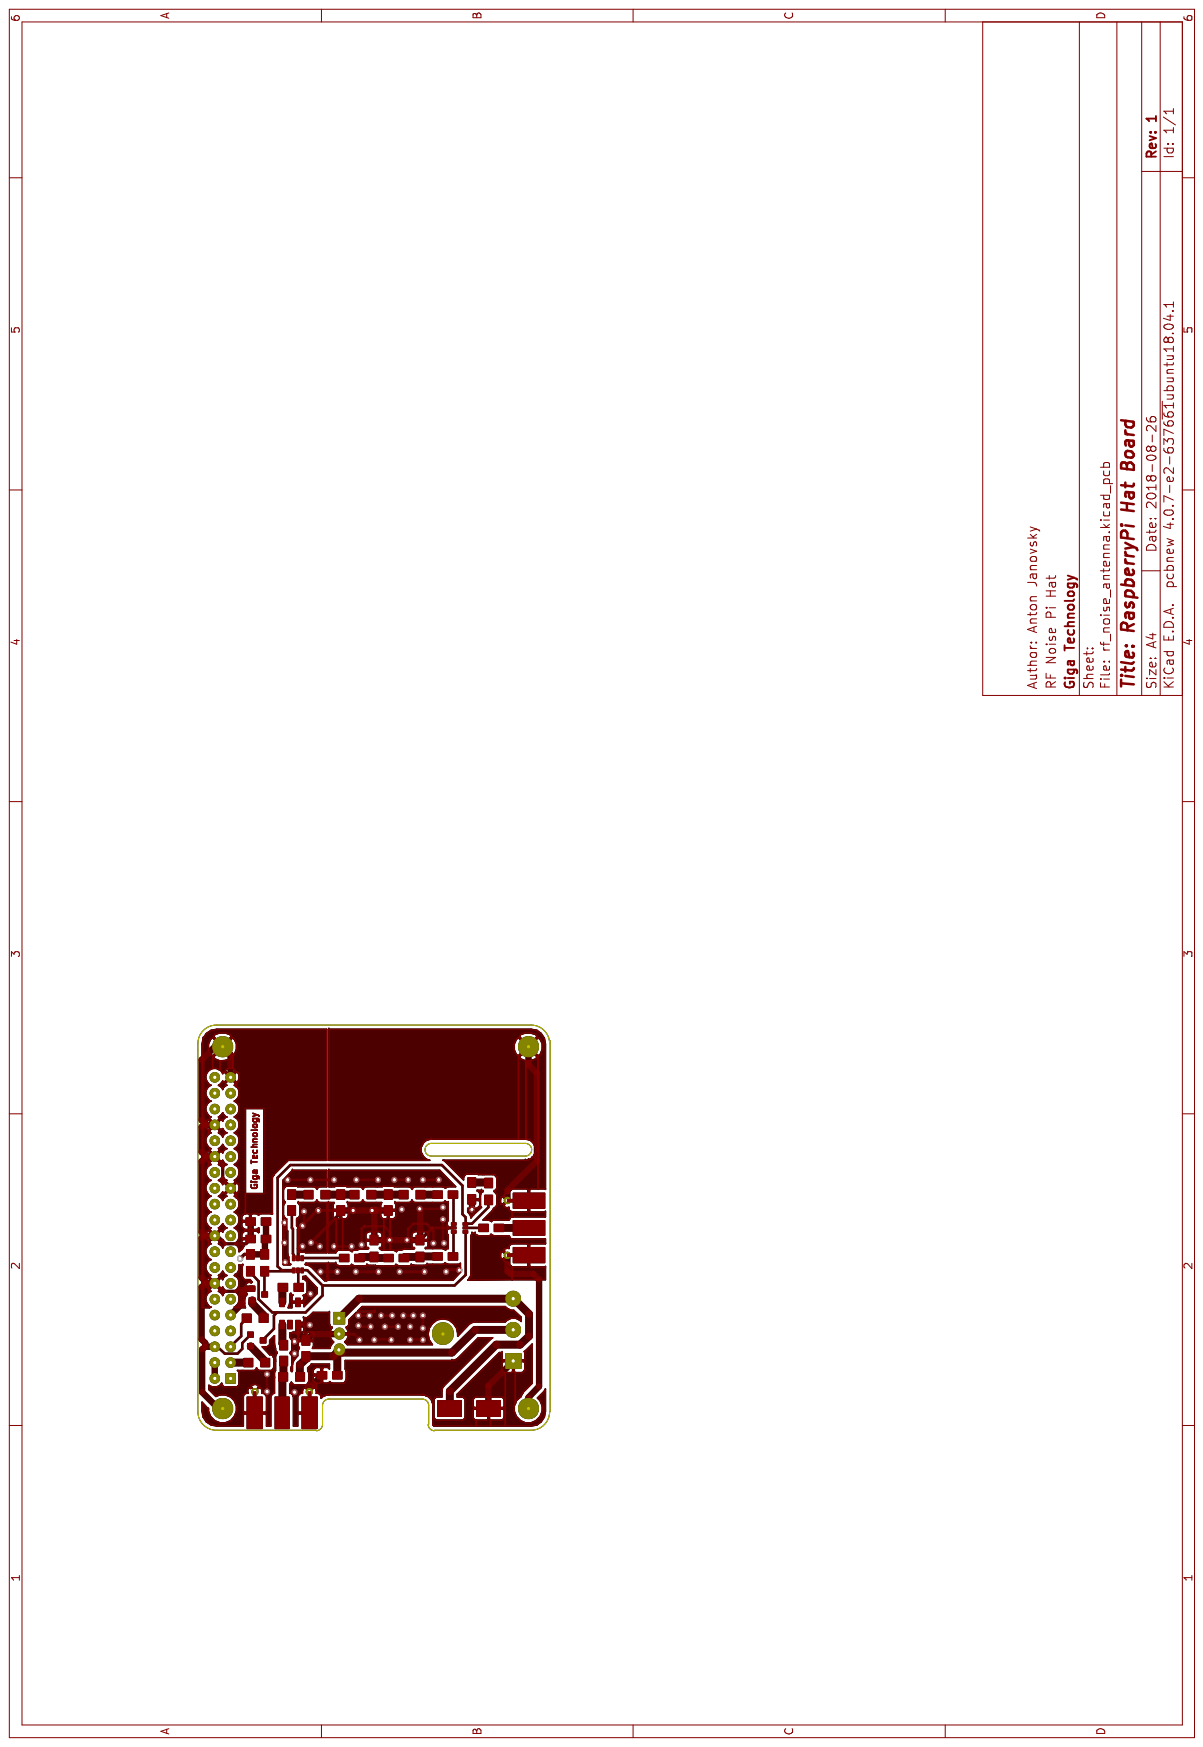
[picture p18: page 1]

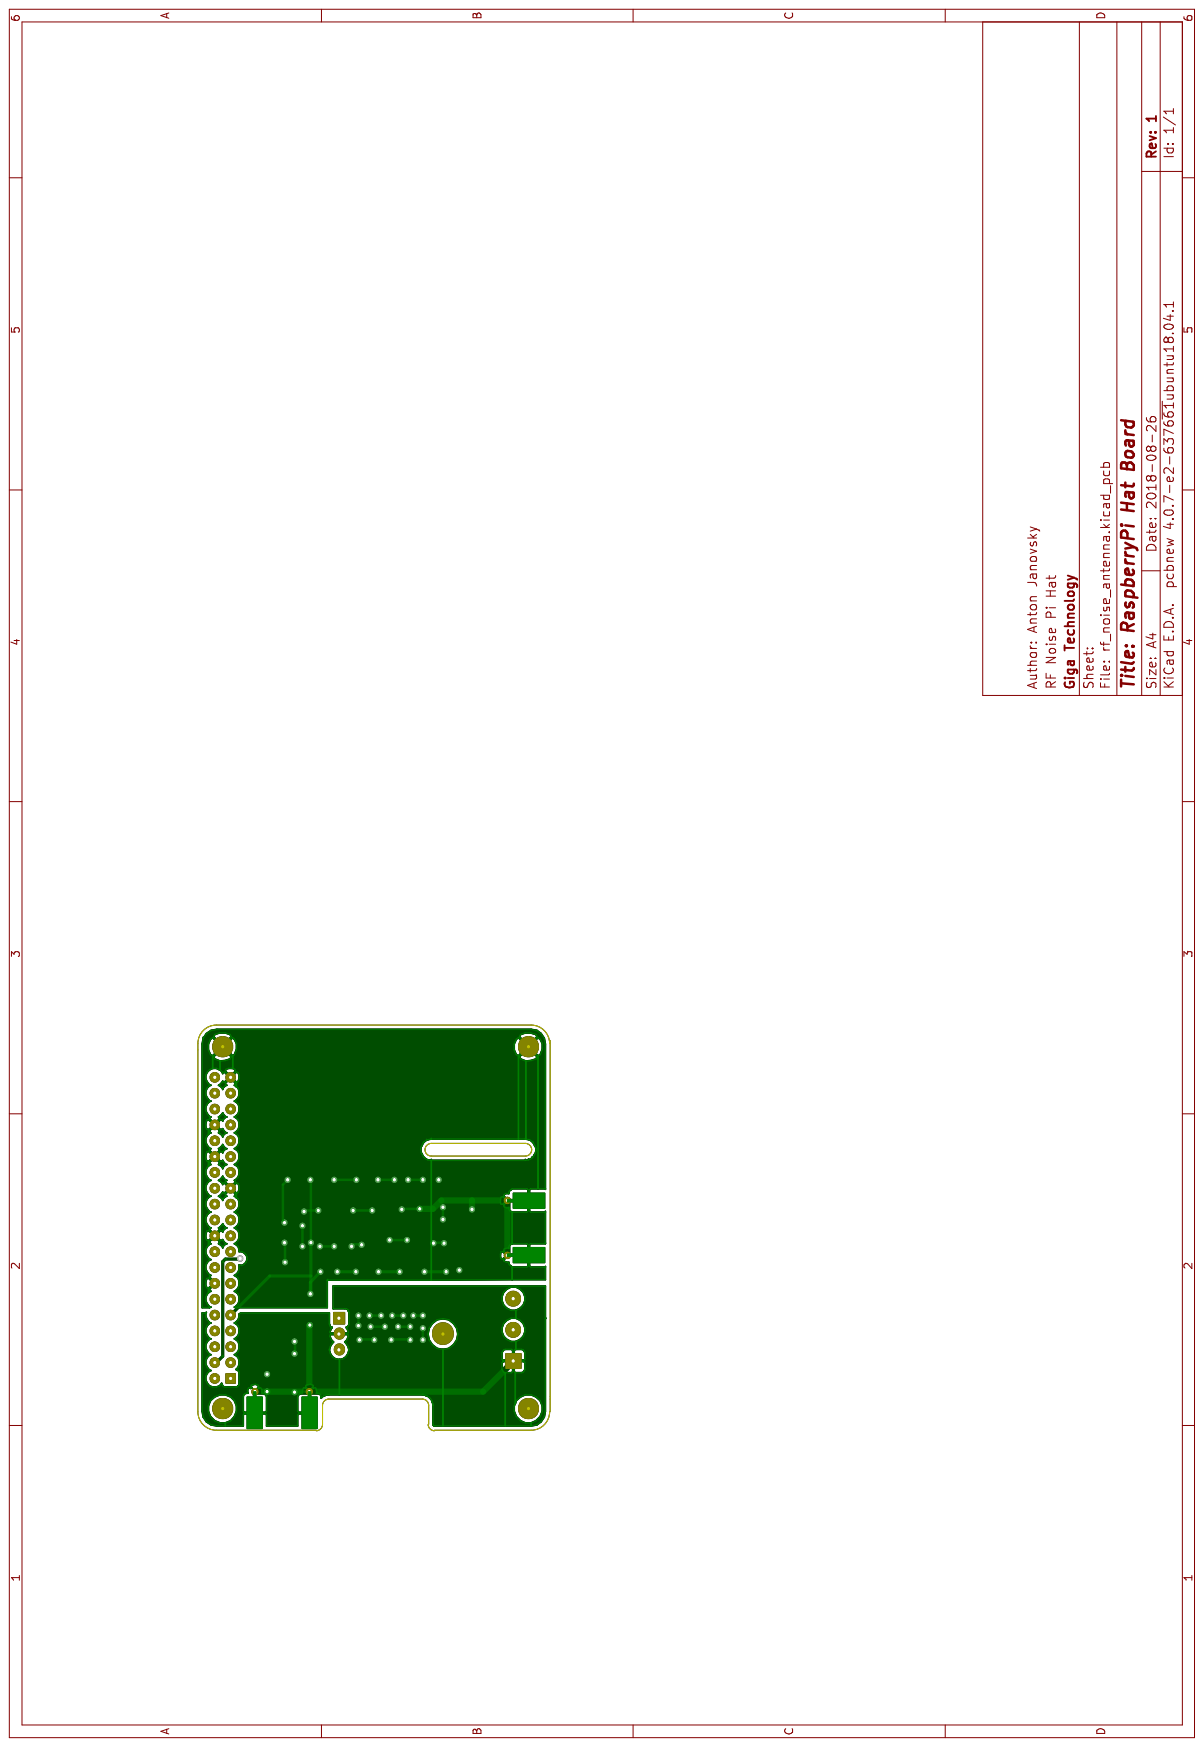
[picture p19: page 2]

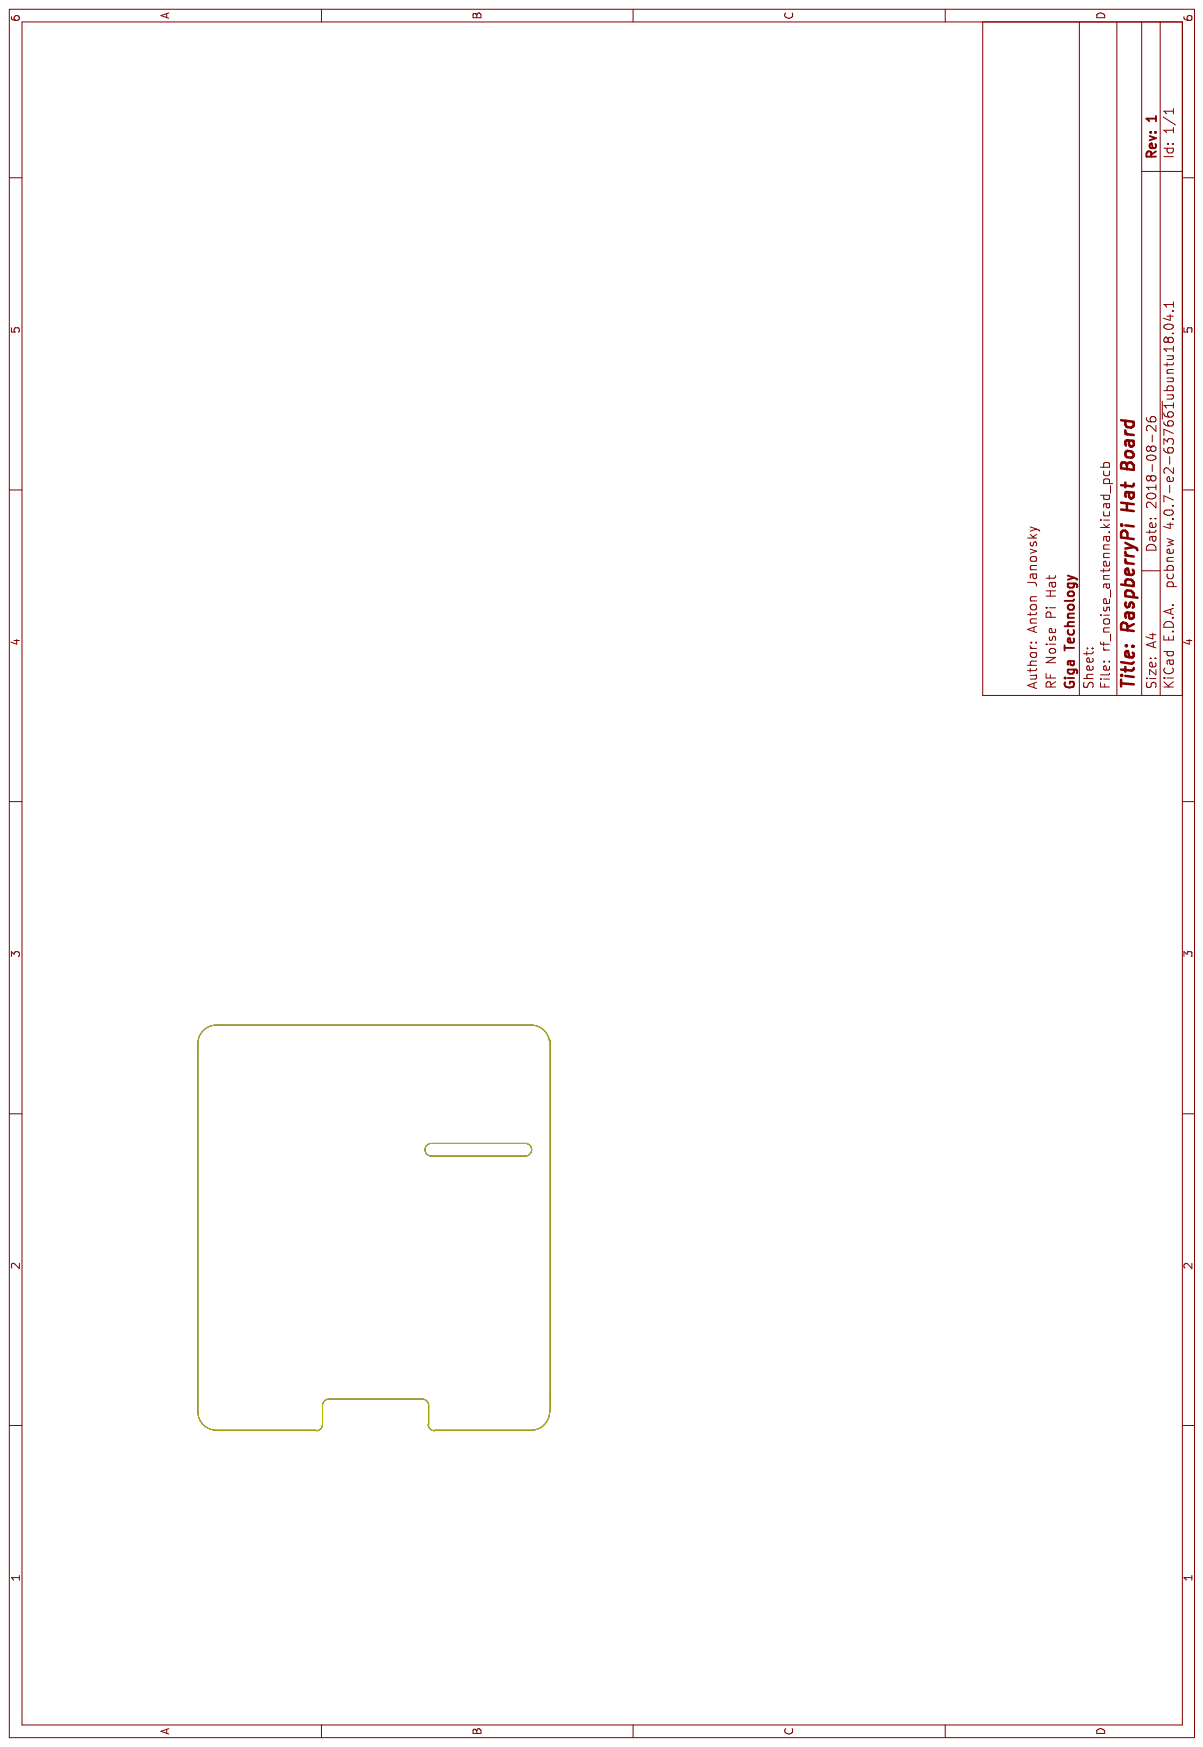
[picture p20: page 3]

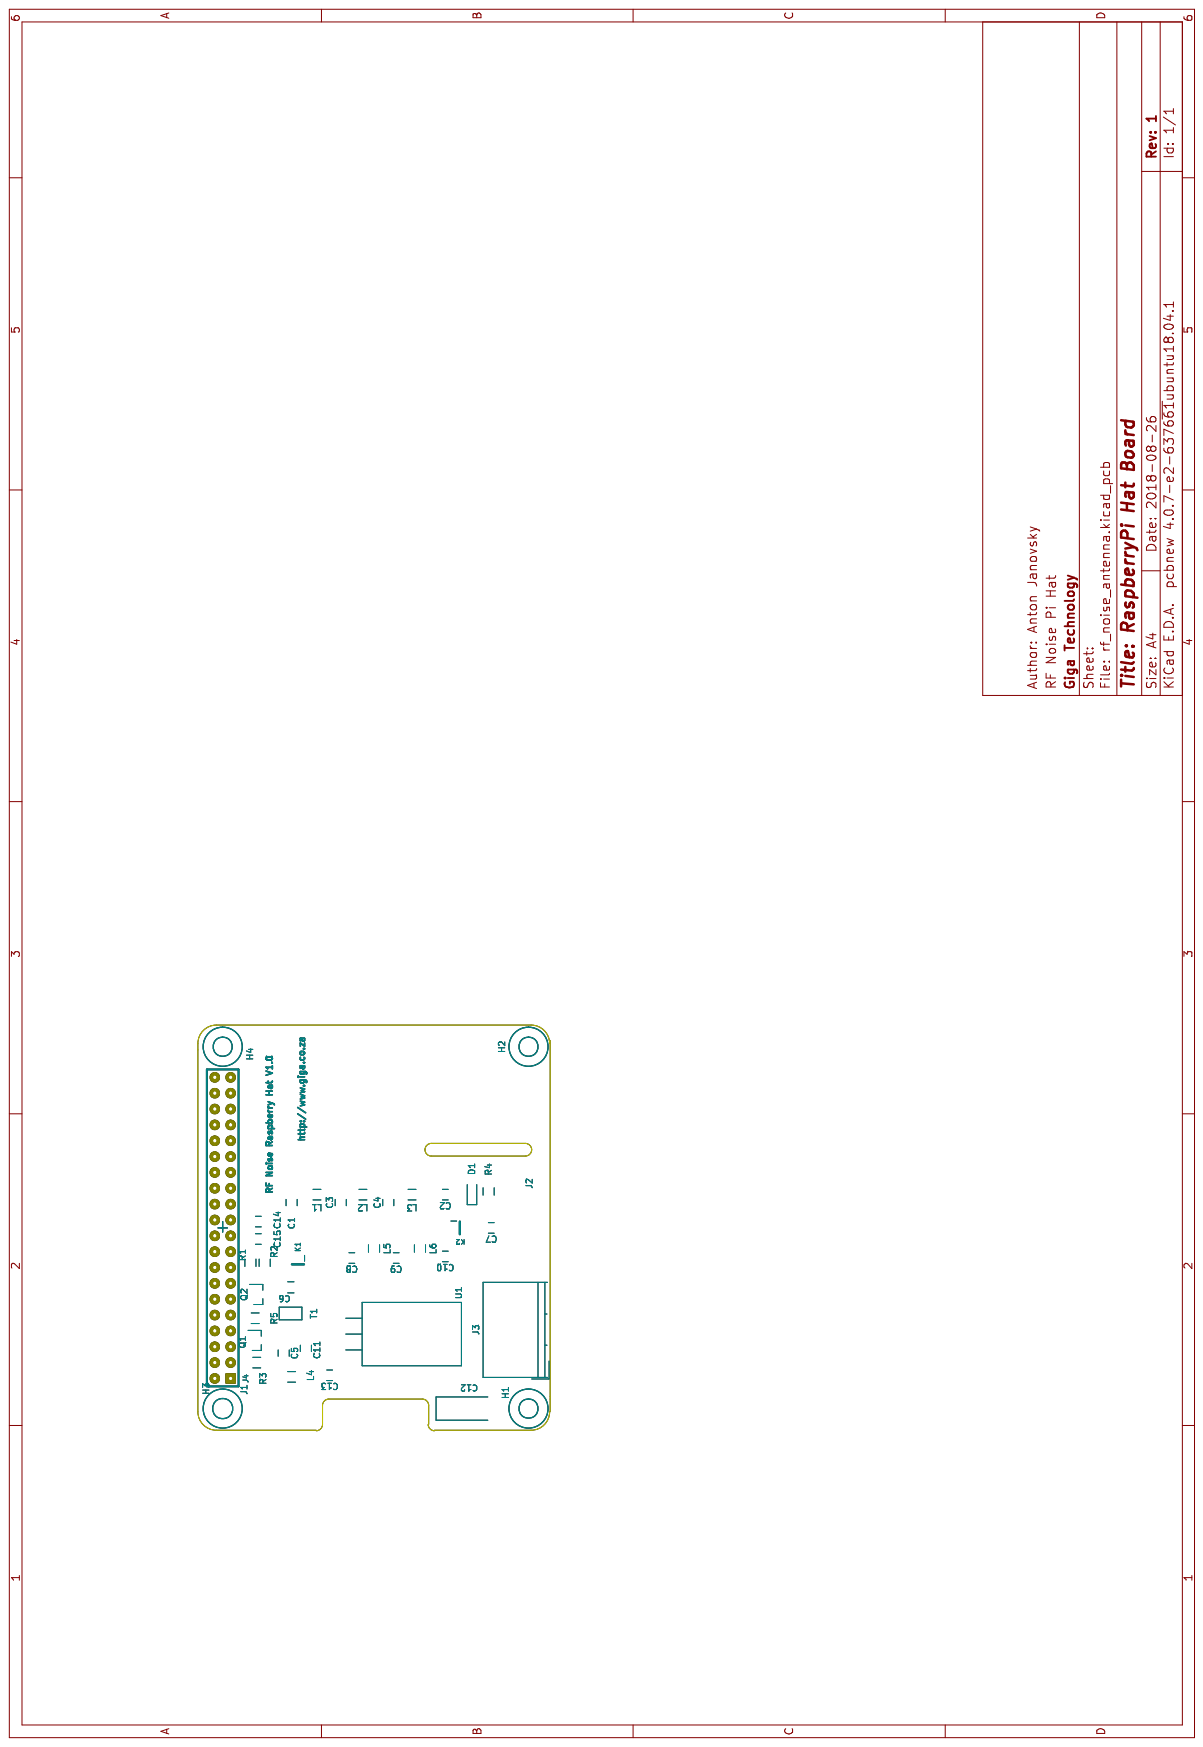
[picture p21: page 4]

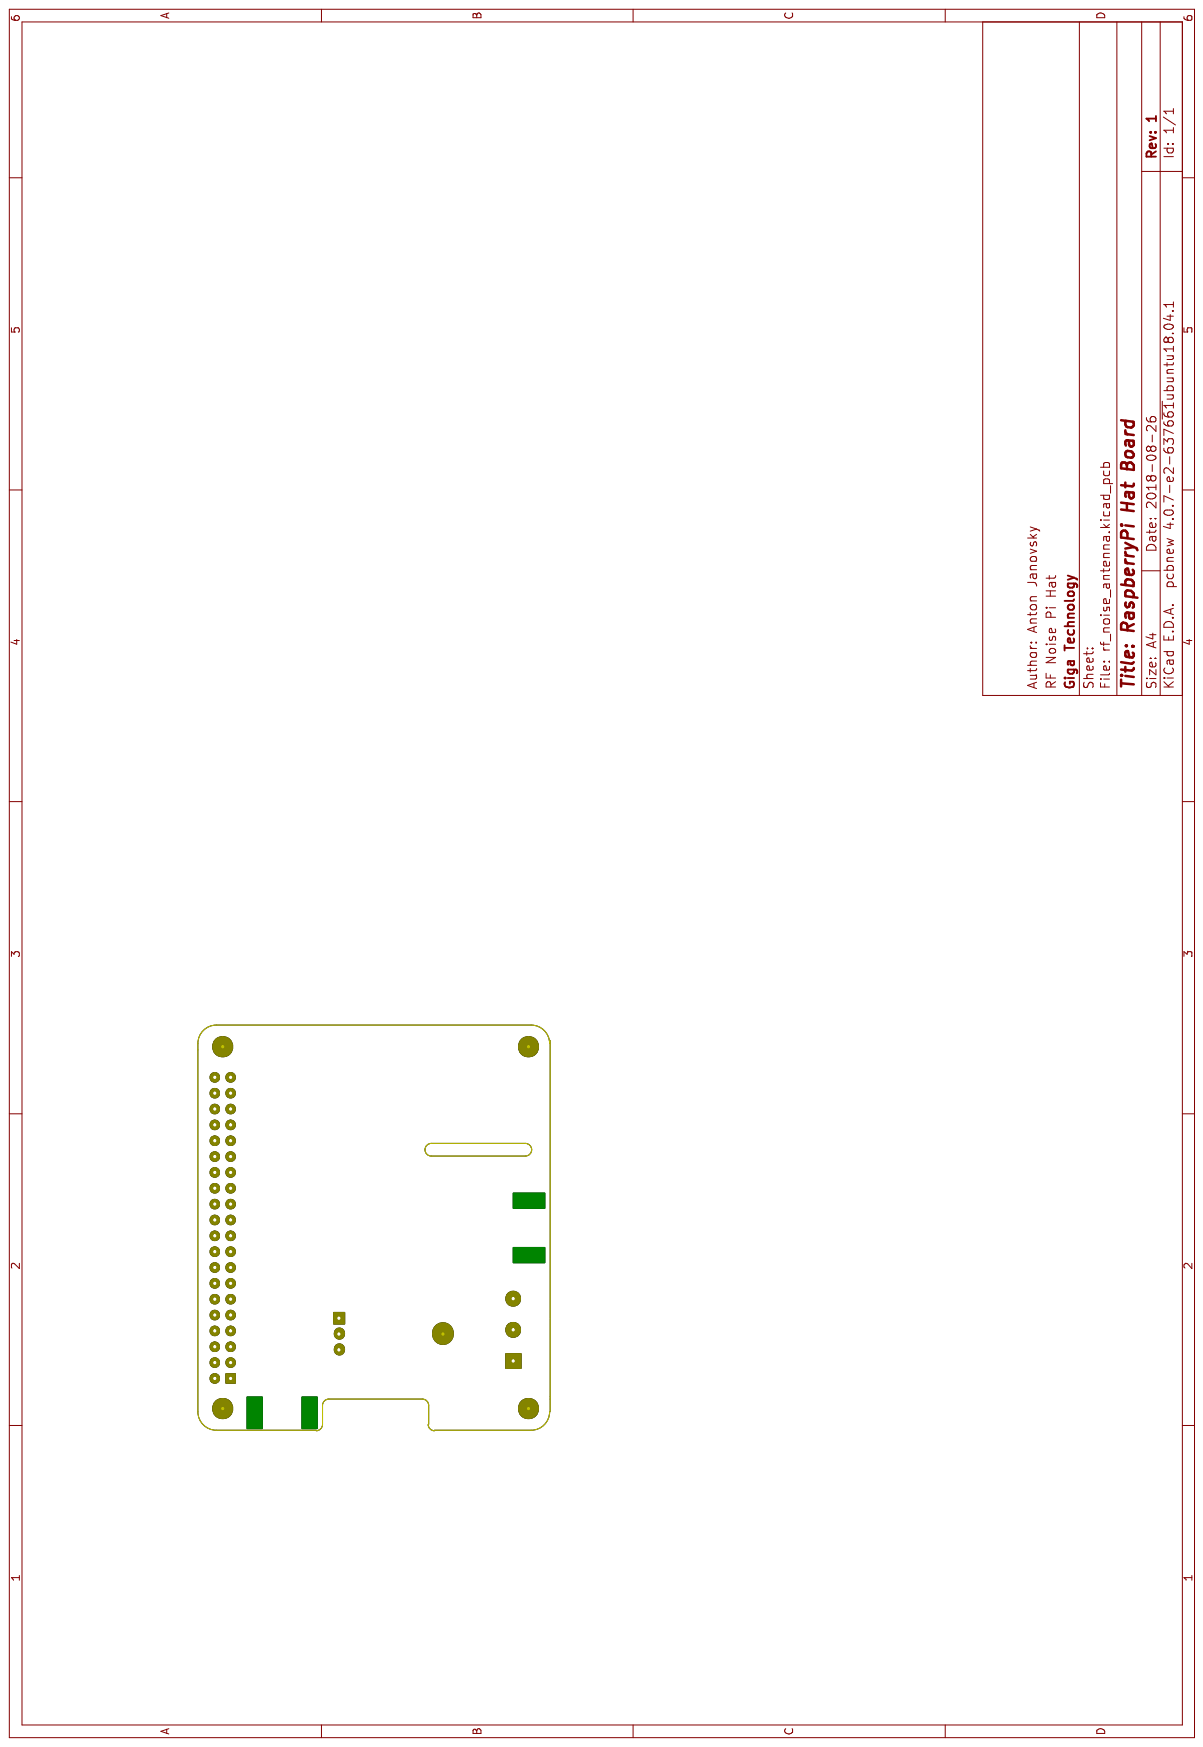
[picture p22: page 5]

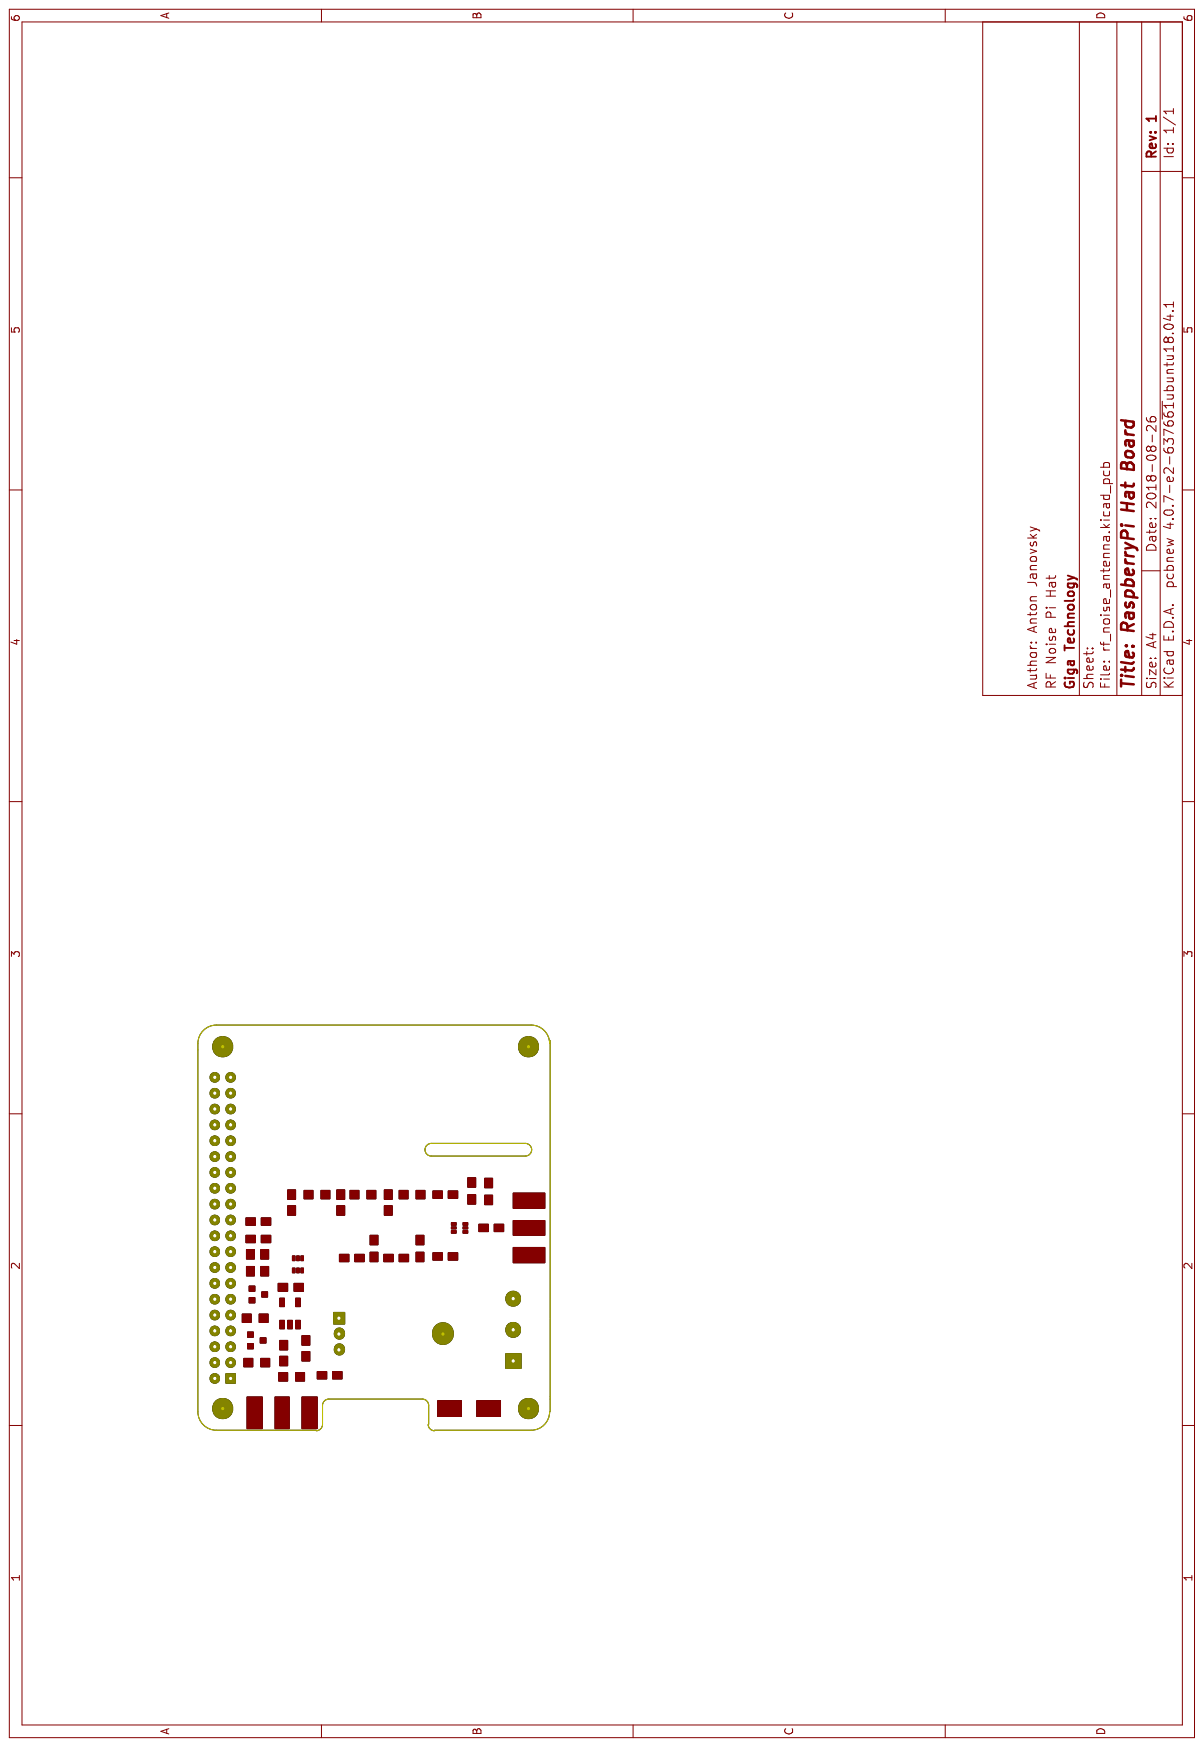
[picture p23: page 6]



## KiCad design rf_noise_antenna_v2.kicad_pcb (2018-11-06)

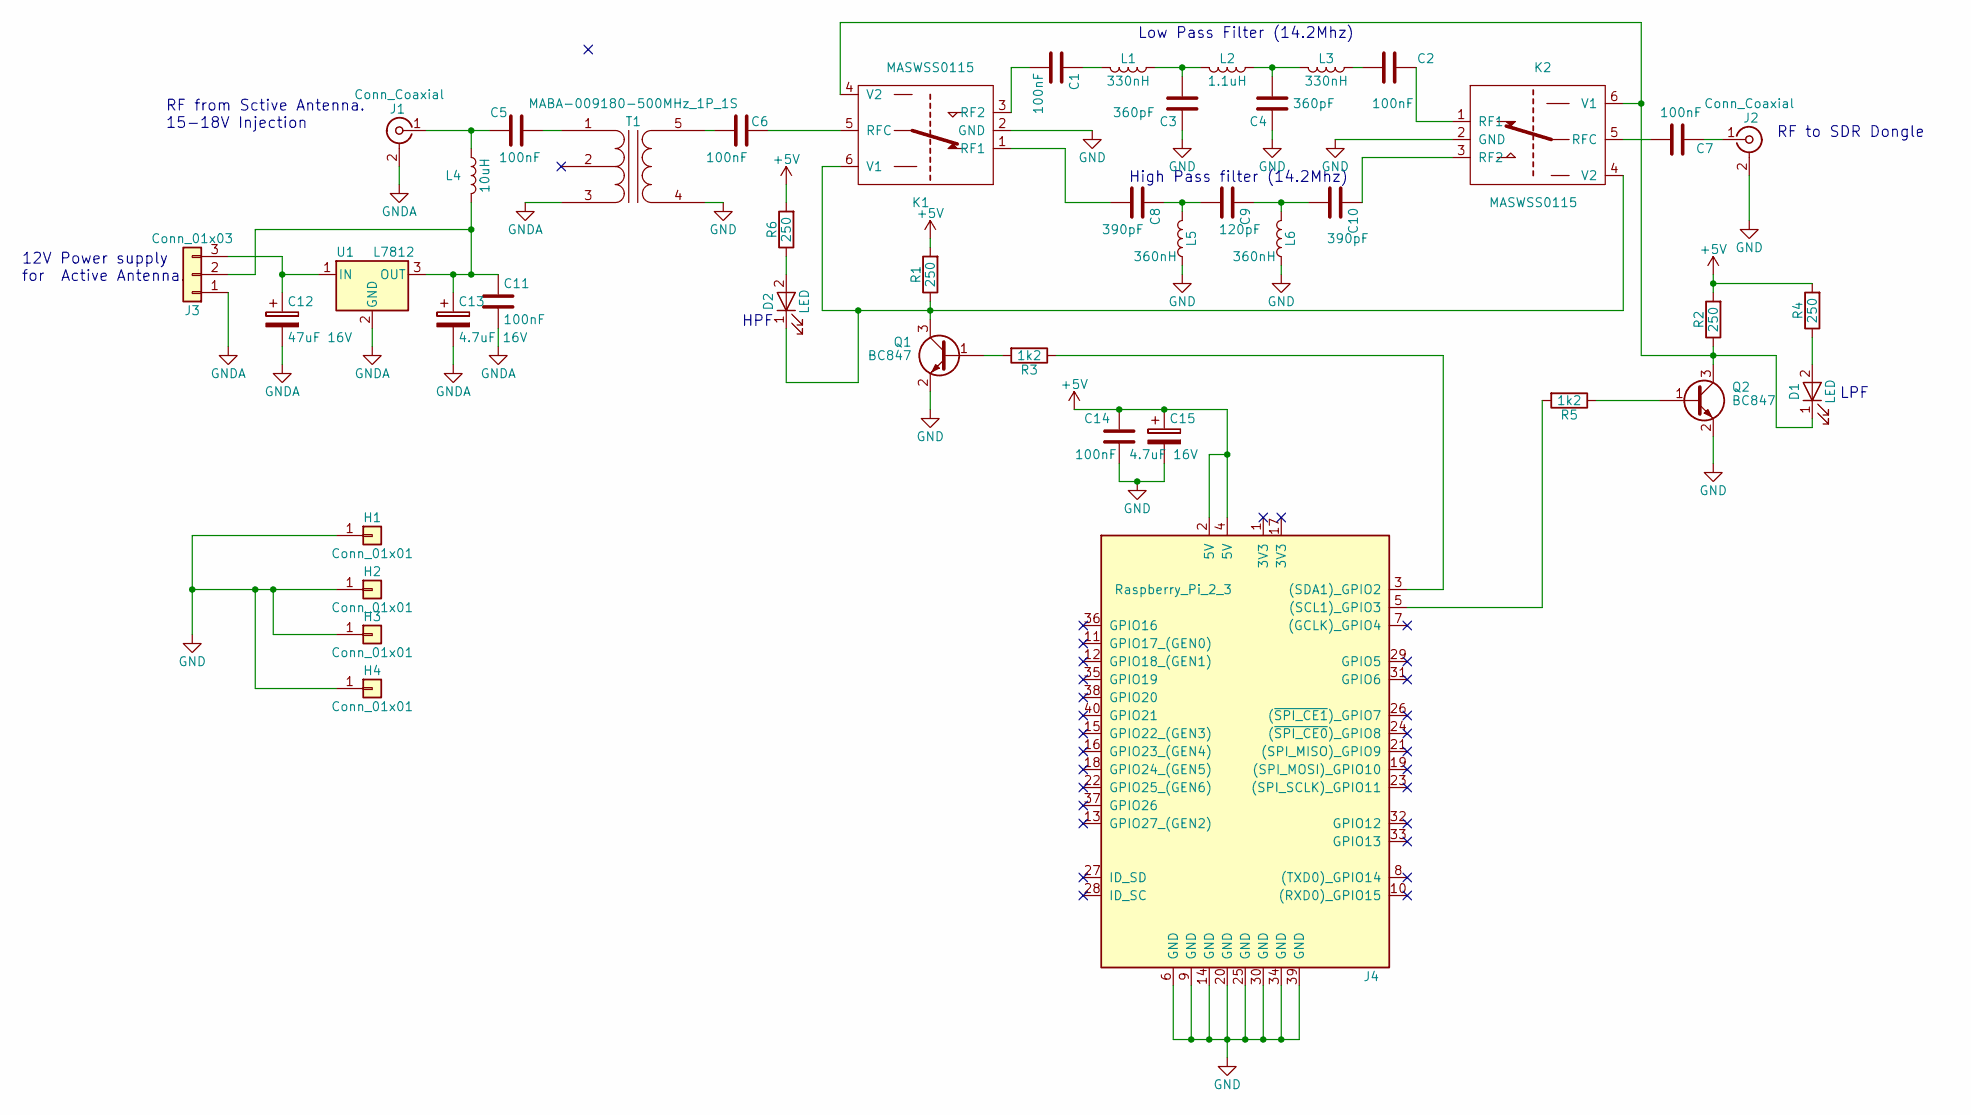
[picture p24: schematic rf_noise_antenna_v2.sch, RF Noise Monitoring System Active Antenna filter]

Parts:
C1, C2, C5, C6, C7, C11, C14: 100nF; C_0805_HandSoldering
C3, C4: 360pF; C_0805_HandSoldering
C8, C10: 390pF; C_0805_HandSoldering
C9: 120pF; C_0805_HandSoldering
C12: 47uF 16V; CP_Tantalum_Case-C_EIA-6032-28_Hand
C13, C15: 4.7uF 16V; C_0805_HandSoldering
D1, D2: LED; LED_0805_HandSoldering
H1, H2, H3, H4: Conn_01x01; MountingHole_3.2mm_M3
J1, J2: Conn_Coaxial; SMA_Edge
J3: Conn_01x03; TerminalBlock_Philmore_TB133_03x5mm_Straight
J4: Raspberry_Pi_2_3; Pin_Header_Straight_2x20
K1, K2: MASWSS0115; SC-70-6
L1, L3: 330nH; L_0805_HandSoldering
L2: 1.1uH; L_0805_HandSoldering
L4: 10uH; L_0805_HandSoldering
L5, L6: 360nH; L_0805_HandSoldering
Q1, Q2: BC847; SOT-23
R1, R2, R4, R6: 250; R_0805_HandSoldering
R3, R5: 1k2; R_0805_HandSoldering
T1: MABA-009180-500MHz_1P_1S; SM22
U1: L7812; TO-220_Horizontal

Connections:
+5V: C14.1, C15.1, J4.2 (5V), J4.4 (5V), R1.2, R2.2, R4.2, R6.2
GND: C3.1, C4.1, C14.2, C15.2, H1.1, H2.1, H3.1, H4.1, J2.2 (Ext), J4.6 (GND), J4.9 (GND), J4.14 (GND), J4.20 (GND), J4.25 (GND), J4.30 (GND), J4.34 (GND), J4.39 (GND), K1.2 (GND), K2.2 (GND), L5.1, L6.1, Q1.2 (E), Q2.2 (E), T1.4 (SB)
GNDA: C11.2, C12.2, C13.2, J1.2 (Ext), J3.1, T1.3 (SA), U1.2 (GND)
unnamed: C1.1, L1.2
unnamed: C1.2, K1.3 (RF2)
unnamed: C2.1, K2.1 (RF1)
unnamed: C2.2, L3.1
unnamed: C3.2, L1.1, L2.2
unnamed: C4.2, L2.1, L3.2
unnamed: C5.1, T1.1 (AA)
unnamed: C5.2, J1.1 (In), L4.1
unnamed: C6.1, K1.5 (RFC)
unnamed: C6.2, T1.5 (S)
unnamed: C7.1, J2.1 (In)
unnamed: C7.2, K2.5 (RFC)
unnamed: C8.1, C9.2, L5.2
unnamed: C8.2, K1.1 (RF1)
unnamed: C10.1, K2.3 (RF2)
unnamed: C9.1, C10.2, L6.2
unnamed: C11.1, C13.1, J3.2, L4.2, U1.3 (OUT)
unnamed: C12.1, J3.3, U1.1 (IN)
unnamed: D1.1 (K), K1.4 (V2), K2.6 (V1), Q2.3 (C), R2.1
unnamed: D1.2 (A), R4.1
unnamed: D2.1 (K), K1.6 (V1), K2.4 (V2), Q1.3 (C), R1.1
unnamed: D2.2 (A), R6.1
unnamed: J4.3 ((SDA1)_GPIO2), R3.1
unnamed: J4.5 ((SCL1)_GPIO3), R5.2
unnamed: Q1.1 (B), R3.2
unnamed: Q2.1 (B), R5.1

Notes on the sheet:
High Pass filter (14.2Mhz)
Low Pass Filter (14.2Mhz)
RF to SDR Dongle
RF from Sctive Antenna. 15-18V Injection
12V Power supply for Active Antenna.
HPF
LPF

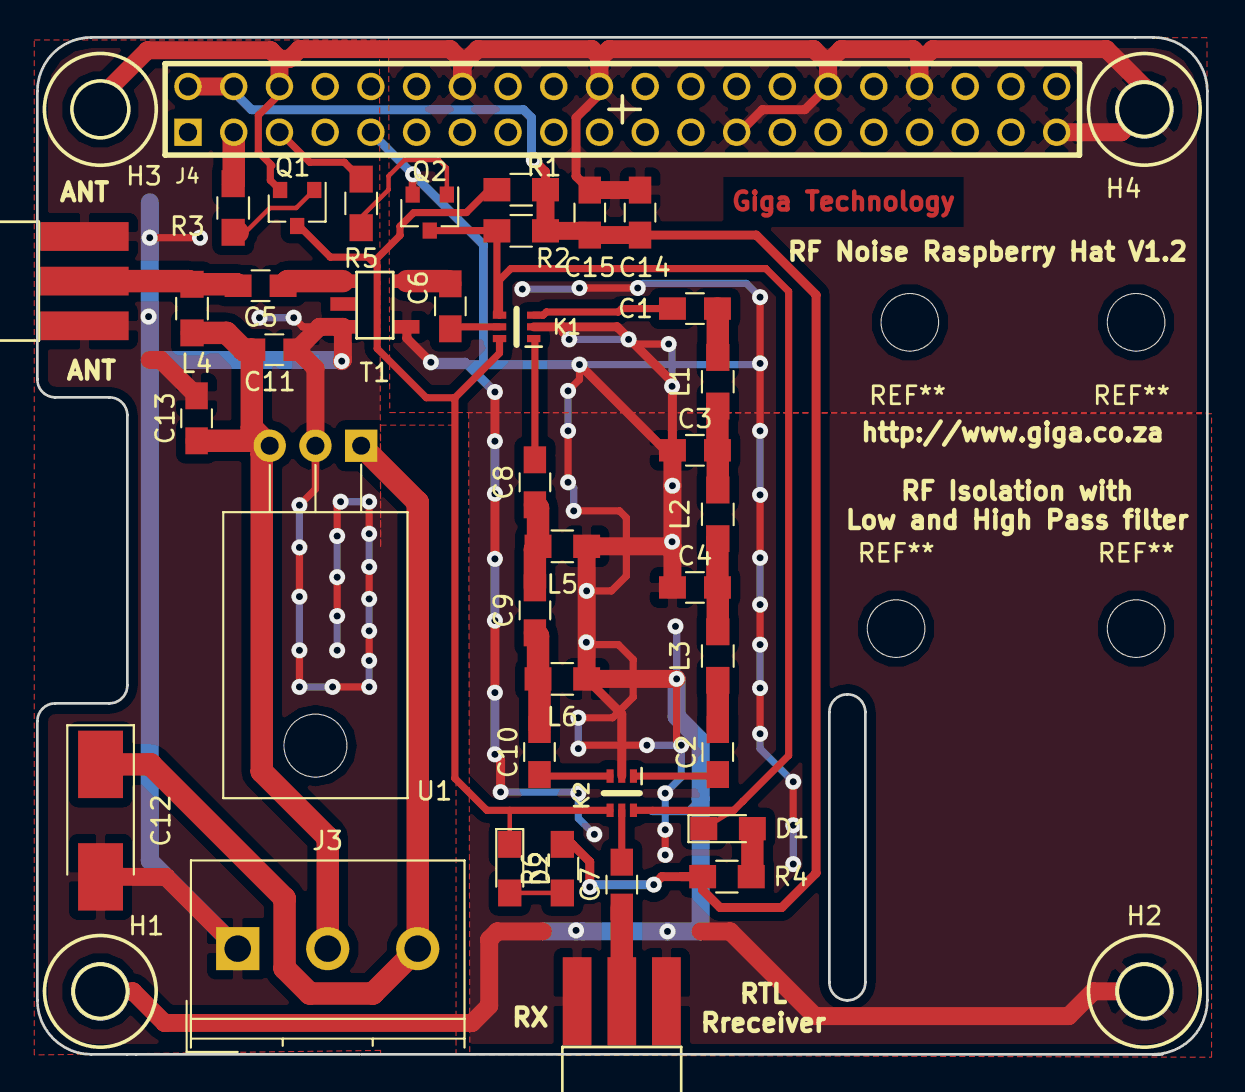
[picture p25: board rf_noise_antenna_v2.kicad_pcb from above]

Board: 2 copper layers, 65.0 x 56.5 mm, 43 parts (0 on the bottom side), 29 nets.

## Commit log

2018-08-17 Added diagram
    [rf_noise_antenna.kicad_pcb, rf_noise_antenna.sch]
2018-08-17 adding com Values
    [rf_noise_antenna.sch]
2018-08-17 Change isolation to be at antenna
    [rf_noise_antenna.sch]
2018-08-17 Fix DR cherck
    [rf_noise_antenna.sch]
2018-08-18 Added filter details
2018-08-19 Creating rf relay
2018-08-19 Replace relay with Solit state
    [rf_noise_antenna.sch]
2018-08-21 add componet ref
    [rf_noise_antenna.sch]
2018-08-25 Starting with PCB Layout
    [RPi_Hat.kicad_pcb, rf_noise_antenna.sch]
2018-08-26 Compleet pcb
    [_saved_rf_noise_antenna.sch, rf_noise_antenna.kicad_pcb]
2018-08-26 Added measurmets
    [rf_noise_antenna.kicad_pcb]
2018-08-26 Fix Transistor pin config
    [rf_noise_antenna.kicad_pcb, rf_noise_antenna.sch]
2018-08-26 adding filter details
2018-08-27 adding pcb_pic
2018-08-27 Fix LED and Inductor value
    [rf_noise_antenna.sch]
2018-08-29 Added Bom file
    [rf_noise_antenna.sch, rf_noise_antenna_V1.0.csv]
2018-08-29 adding Bom details
    [rf_noise_antenna_V1.0_digi_key.xlsx]
2018-10-25 Added active Antenna
    [rf_noise_antenna.sch]
2018-10-25 Added anotation for active Antenna
    [rf_noise_antenna.sch]
2018-11-06 adding V2 files
    [rf_noise_antenna.csv, rf_noise_antenna.kicad_pcb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]
2018-11-22 add pin direction
